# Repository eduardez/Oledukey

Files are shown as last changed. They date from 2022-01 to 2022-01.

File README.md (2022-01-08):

# Oledukey
Aun en fase de diseño, pero pinta flama.

# Renders
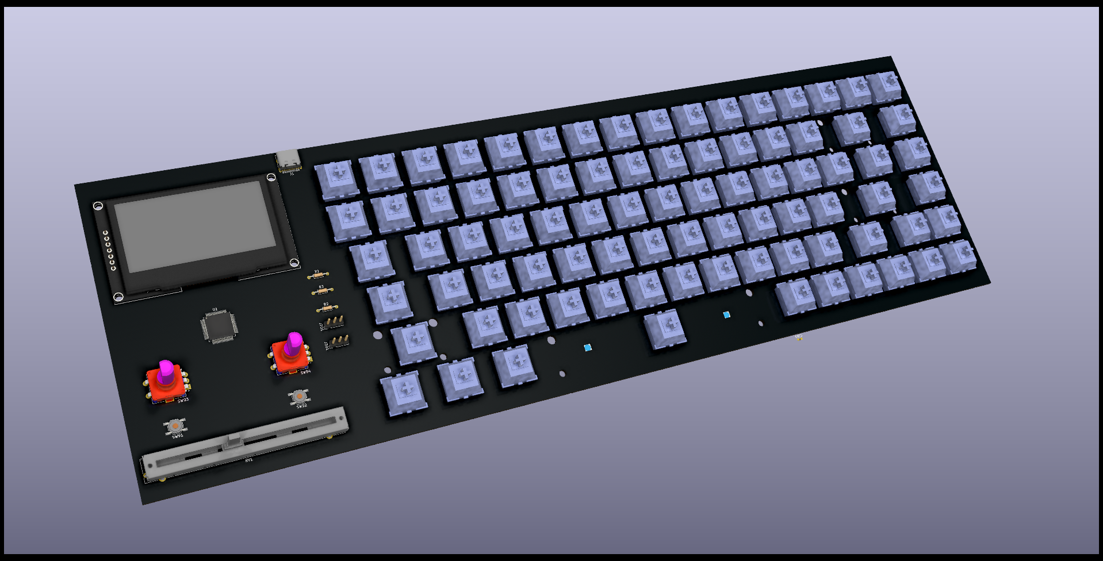
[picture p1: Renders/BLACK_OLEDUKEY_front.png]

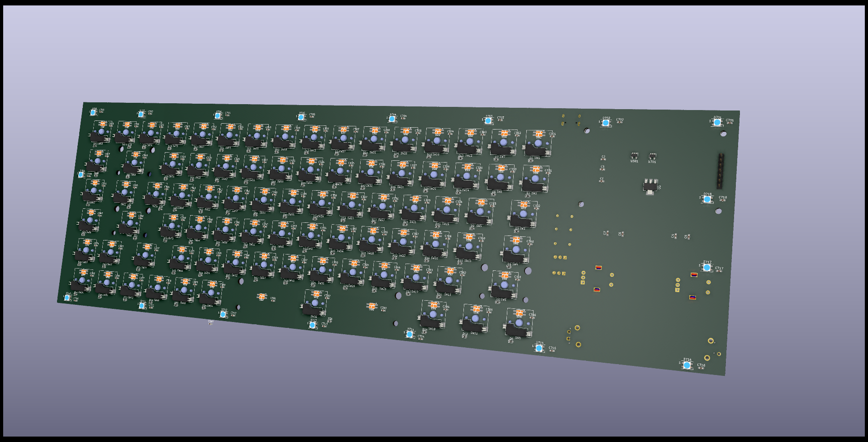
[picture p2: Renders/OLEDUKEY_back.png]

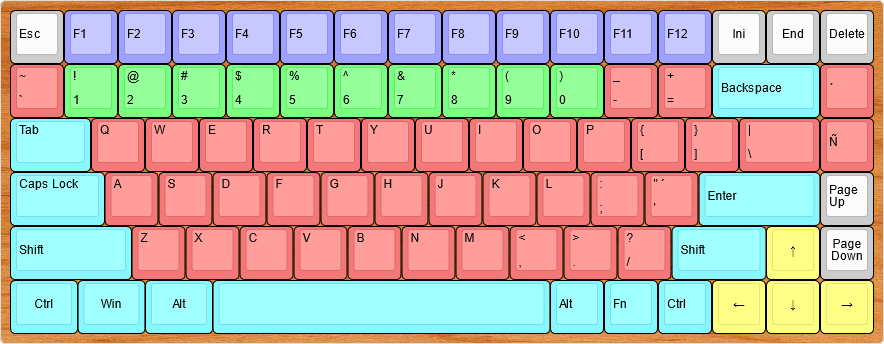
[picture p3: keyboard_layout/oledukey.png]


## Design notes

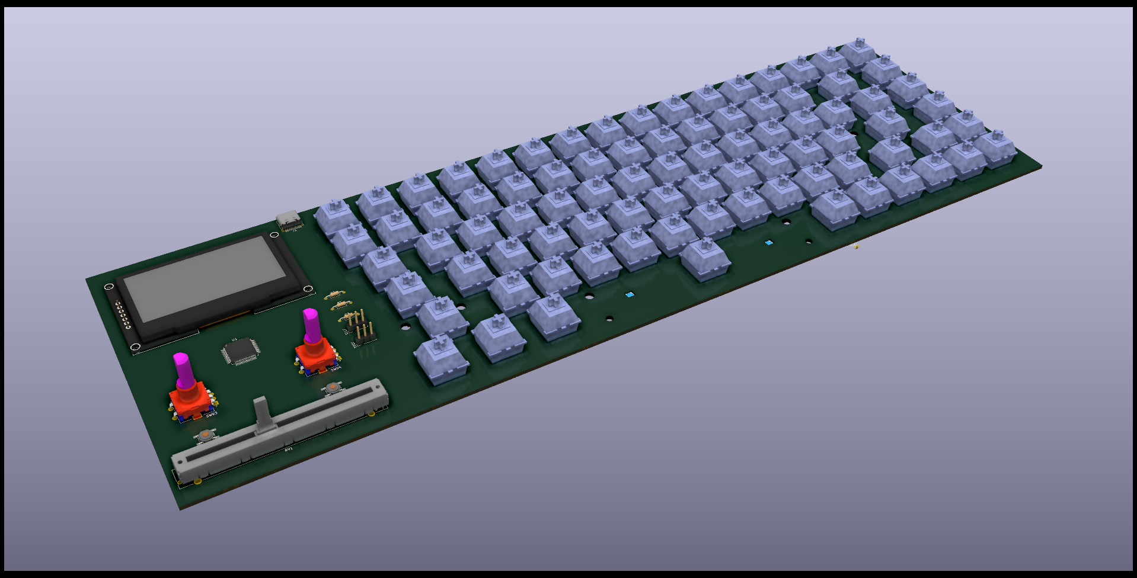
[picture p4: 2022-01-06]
Renders/OLEDUKEY_front.png

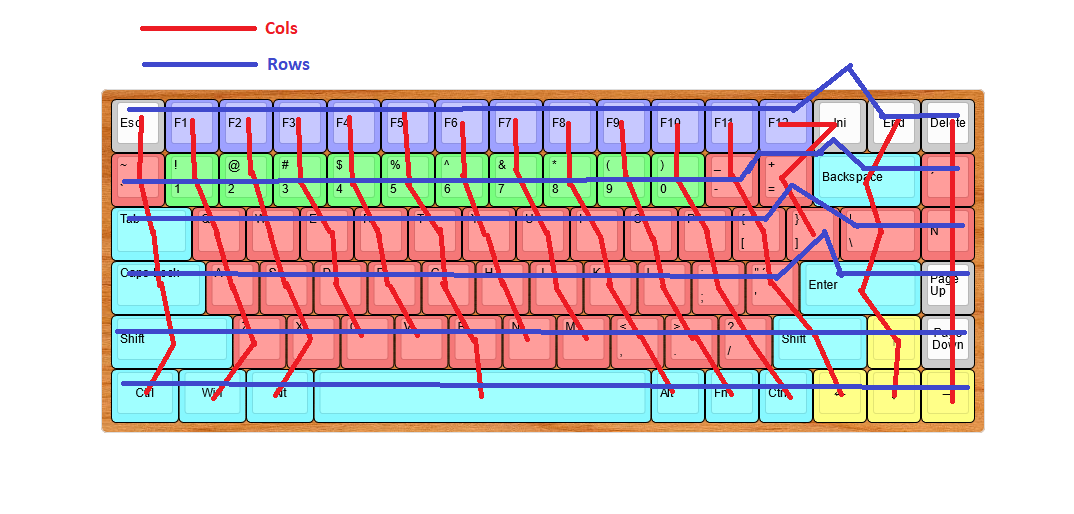
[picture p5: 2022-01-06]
keyboard_layout/oledukeyMATRIX.png

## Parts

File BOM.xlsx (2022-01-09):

Comprado | Parte | Valor | Quantity | Total buy | Value/unit | Total Price | Buy | Datasheet
 | Capacitor | 100nF | 109 |  | 0.0027 | 0.2943 | https://lcsc.com/product-detail/Multilayer-Ceramic-Capacitors-MLCC-SMD-SMT_FH-Guangdong-Fenghua-Advanced-Tech-0603F104M500NT_C42998.html | https://datasheet.lcsc.com/lcsc/1809211526_FH-Guangdong-Fenghua-Advanced-Tech-0603F104M500NT_C42998.pdf
 | Capacitor | 10uF | 2 |  | 0.0055 | 0.011 | https://lcsc.com/product-detail/Multilayer-Ceramic-Capacitors-MLCC-SMD-SMT_Samsung-Electro-Mechanics-CL10A106MP8NNNC_C85713.html | https://datasheet.lcsc.com/lcsc/1811021421_Samsung-Electro-Mechanics-CL10A106MP8NNNC_C85713.pdf
 | Diode | 1N4148WS | 84 |  | 0.0117 | 0.9828 | https://lcsc.com/product-detail/Switching-Diode_Shikues-1N4148WS_C110221.html | https://datasheet.lcsc.com/lcsc/1811131825_Shikues-1N4148WS_C110221.pdf
 | LED | SK6812MINI | 86 |  | 0.1147 | 9.8642 | https://es.aliexpress.com/item/32782295214.html | https://cdn-shop.adafruit.com/product-files/2686/SK6812MINI_REV.01-1-2.pdf
 | LED | SK6812MINI | 18 |  | 0.1099 | 1.9782 | https://es.aliexpress.com/item/32782295214.html | https://cdn-shop.adafruit.com/product-files/2686/SK6812MINI_REV.01-1-2.pdf
 | Connector | USB_C_TYPE-C-31-M-12 | 1 |  | 0.2453 | 0.2453 | https://lcsc.com/product-detail/USB-Connectors_Korean-Hroparts-Elec-TYPE-C-31-M-12_C165948.html | https://datasheet.lcsc.com/lcsc/2108131730_Korean-Hroparts-Elec-TYPE-C-31-M-12_C165948.pdf
 | Connector | Conn_01x03 | 2 |  | 0 | 0 | Home | ~
 | Resistor | 10k | 1 |  | 0 | 0 | Home | ~
 | Resistor | 5.1k | 2 |  | 0 | 0 | Home | ~
 | Potentiometer slide | R_POT | 1 |  | 11 | 11 | https://es.aliexpress.com/item/4000135544623.html | https://www.mouser.es/datasheet/2/54/pta-778345.pdf
 | Kalih hotswap | Kalih hotswap | 84 |  | 0.1 | 8.4 | https://kbdfans.com/products/mechanical-keyboard-switches-kailh-pcb-socket?variant=39678399447179 | ~
 | Stabilizers | Stabilizers | 1 |  | 15.9 | 15.9
 | Gatheron red | SW_Push | 84 |  | 0.2 | 16.8 |  | ~
 | Switch push | SW_Push | 2 |  | 0.3896 | 0.7792 | https://lcsc.com/product-detail/Tactile-Switches_E-Switch-TL3342F160QG_C2886898.html | https://datasheet.lcsc.com/lcsc/2109061530_E-Switch-TL3342F160QG_C2886898.pdf
 | Enconder | Rotary_Encoder_Switch | 2 |  | 0.32 | 0.64 | https://es.aliexpress.com/item/1744383771.html | https://www.farnell.com/datasheets/1837001.pdf
 | Brain | STM32F072RBTx | 1 |  | 12.4 | 12.4 | https://es.aliexpress.com/item/4001114352067.html | http://www.st.com/st-web-ui/static/active/en/resource/technical/document/datasheet/DM00090510.pdf
 | OLED | 2.42OLED | 1 |  | 17.77 | 17.77 | https://es.aliexpress.com/item/32965834123.html
 | Volt. Regulator | AMS1117-3.3 | 1 |  | 0.0852 | 0.0852 | https://lcsc.com/product-detail/Linear-Voltage-Regulators-LDO_PUOLOP-AMS1117-3-3_C351784.html | http://www.advanced-monolithic.com/pdf/ds1117.pdf
 | Buffered driver | 74LVC1G125 | 2 |  | 0.0791 | 0.1582 | https://lcsc.com/product-detail/Buffers-Drivers_Texas-Instruments-SN74LVC1G125DBVR_C23654.html | https://datasheet.lcsc.com/lcsc/1809200051_Texas-Instruments-SN74LVC1G125DBVR_C23654.pdf
 | PCB | Oledukey | 1 |  | 15.38 | 15.38
 |  |  | Por teclado
 |  | Total | 112.6884

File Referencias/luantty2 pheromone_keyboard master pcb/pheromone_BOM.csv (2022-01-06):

Comment | Description | Designator | Footprint | LibRef | Pins | Quantity | 긍뵀
LOGO | Desc | G***, | monitor | LibRef | 0 | 1
KiCad-Logo_5mm_Copper | Desc | REF**, | KiCad-Logo_5mm_Copper | LibRef | 0 | 1
WEEE-Logo_4.2x6mm_SilkScreen | Desc | REF**, | WEEE-Logo_4.2x6mm_SilkScreen | LibRef | 0 | 1
22p | Desc | C2,C1, | C_0805_2012Metric | LibRef | 2 | 2
1u | Desc | C3, | C_0805_2012Metric | LibRef | 2 | 1
100n | Desc | C7,C6,C5,C4, | C_0805_2012Metric | LibRef | 2 | 4
4.7u | Desc | C8, | C_0805_2012Metric | LibRef | 2 | 1
D | Desc | D1,D2,D3,D4,D5,D6,D7,D8,D9,D10,D11,D12,D13,D14,D15,D16,D17,D18,D19,D20,D21,D22,D23,D24,D25,D26,D27,D28,D29,D30,D31,D32,D33,D34,D35,D36,D37,D38,D39,D40,D41,D42,D43,D44,D45,D46,D47,D48,D49,D50,D51,D52,D53,D54,D55,D56,D57,D58,D59,D60,D61,D62,D63, | D_SOD-123 | LibRef | 2 | 63
LOGO | Desc | G***, | warning | LibRef | 0 | 1
LOGO | Desc | G***, | brand | LibRef | 0 | 1
LOGO | Desc | G***, | bulb | LibRef | 0 | 1
22 | Desc | R2,R1, | R_0805_2012Metric | LibRef | 2 | 2
10k | Desc | R4,R3, | R_0805_2012Metric | LibRef | 2 | 2
SW_PUSH | Desc | SW1, | SW_DIP_SPSTx01_Slide_6.7x4.1mm_W6.73mm_P2.54mm_LowProfile_JPin | LibRef | 2 | 1
ATMEGA32U4 | Desc | U1, | TQFP-44_10x10mm_Pitch0.8mm | LibRef | 44 | 1
Crystal_GND24 | Desc | Y1, | Crystal_SMD_3225-4Pin_3.2x2.5mm | LibRef | 4 | 1
Through Hole Items
Rotary_Encoder_Switch | Desc | E1, | RotaryEncoder_Alps_EC11E-Switch_Vertical_H20mm | LibRef | 7 | 1
KEYSW | Desc | K13,K56,K1,K2,K3,K4,K5,K6,K7,K8,K9,K10,K11,K12,K14,K15,K17,K18,K19,K20,K21,K22,K23,K24,K25,K26,K27,K28,K30,K31,K32,K33,K34,K35,K36,K37,K38,K39,K40,K41,K44,K45,K46,K47,K48,K49,K50,K51,K52,K53,K54,K55,K61,K62,K63, | MXOnly-1U-Hotswap | LibRef | 7 | 55
KEYSW | Desc | K16, | MXOnly-1.5U-Hotswap | LibRef | 7 | 1
KEYSW | Desc | K29, | MXOnly-1.75U-Hotswap | LibRef | 7 | 1
KEYSW | Desc | K42, | MXOnly-ISO-Hotswap | LibRef | 11 | 1
KEYSW | Desc | K43, | MXOnly-2U-Hotswap-ReversedStabilizers | LibRef | 11 | 1
KEYSW | Desc | K59,K58,K57, | MXOnly-1.25U-Hotswap | LibRef | 7 | 3
KEYSW | Desc | K60, | MXOnly-6.25U-Hotswap-ReversedStabilizers | LibRef | 11 | 1
Conn_01x04 | Desc | O1, | 0.91_SSD1306_OLED | LibRef | 4 | 1
R_POT | Desc | RV1, | potentiometer_slider_45mm | LibRef | 7 | 1
MountingHole_2.2mm_M2 | Desc | [SCREW],[SCREW],[SCREW],[SCREW],[SCREW],[SCREW], | MountingHole_2.2mm_M2 | LibRef | 1 | 6
USB_B_Micro | Desc | J1, | USB_Micro-B_Molex-105017-0001 | LibRef | 13 | 1
AVR-ISP-6 | Desc | P1, | PinHeader_2x03_P2.54mm_Vertical | LibRef | 6 | 1

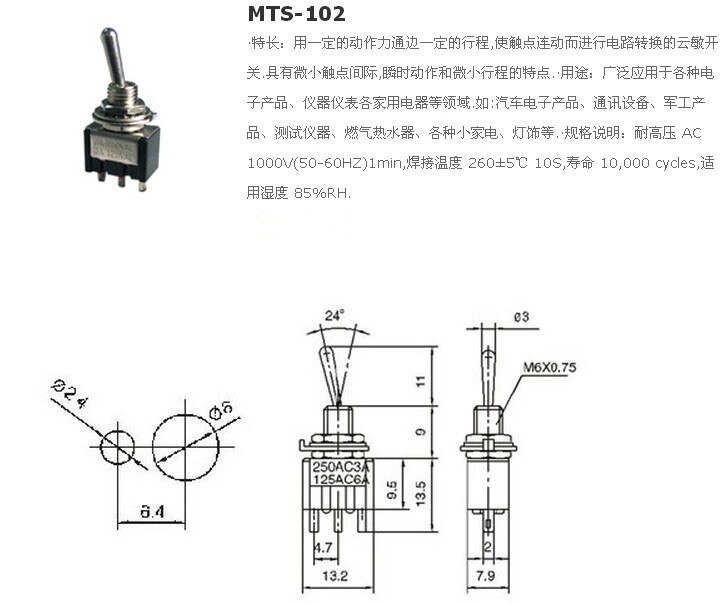
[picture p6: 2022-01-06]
Component sizes/HTB1nNfmtKOSBuNjy0Fdq6zDnVXaB.jpg

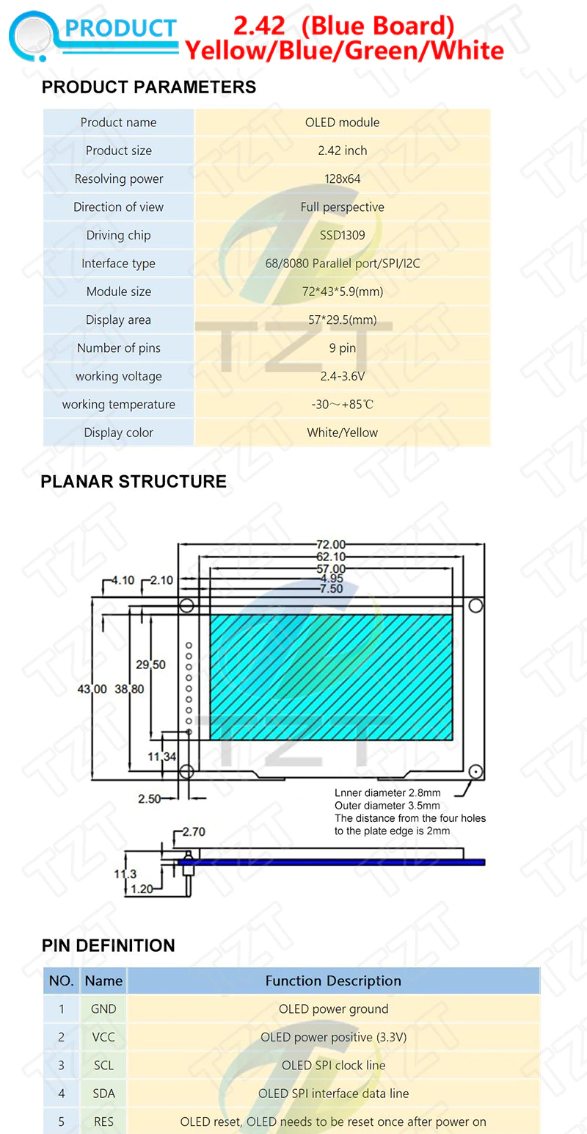
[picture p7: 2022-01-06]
Component sizes/H46aa8765ec844b979cd9eaf251b8d51fb.webp

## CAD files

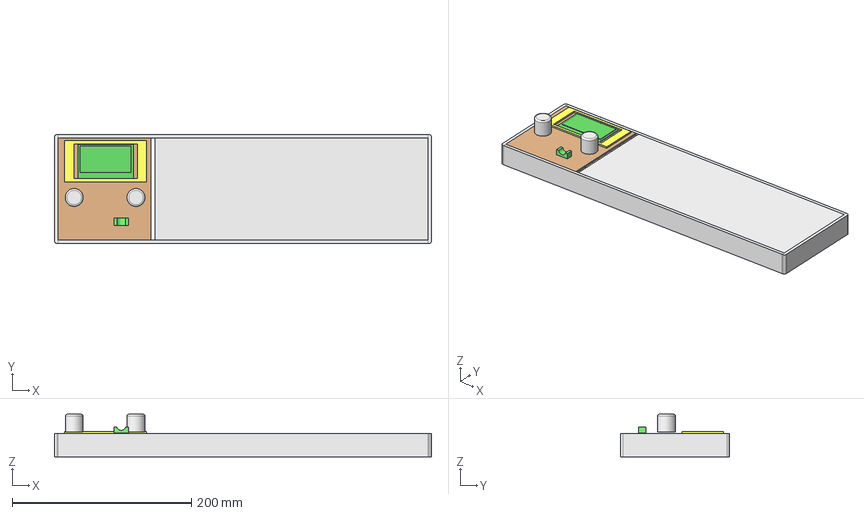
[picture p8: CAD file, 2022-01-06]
teclao_v2.FCStd
421.0 x 122.0 x 47.5 mm
Screen
GuitarCover2
Encoder1
Encoder
Slider
Keys
Mod_plate

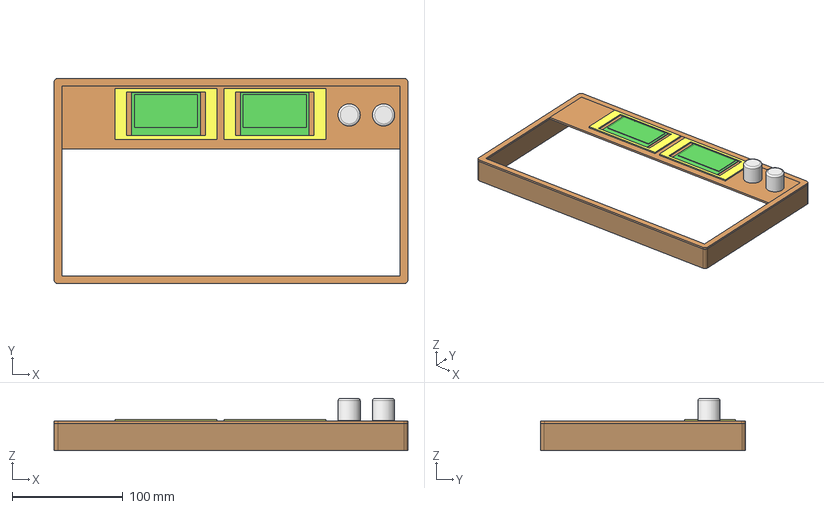
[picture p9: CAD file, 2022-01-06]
teclao.FCStd
319.0 x 185.0 x 47.0 mm
layer_top_2
Cubo002
GuitarCover2
GuitarCover1

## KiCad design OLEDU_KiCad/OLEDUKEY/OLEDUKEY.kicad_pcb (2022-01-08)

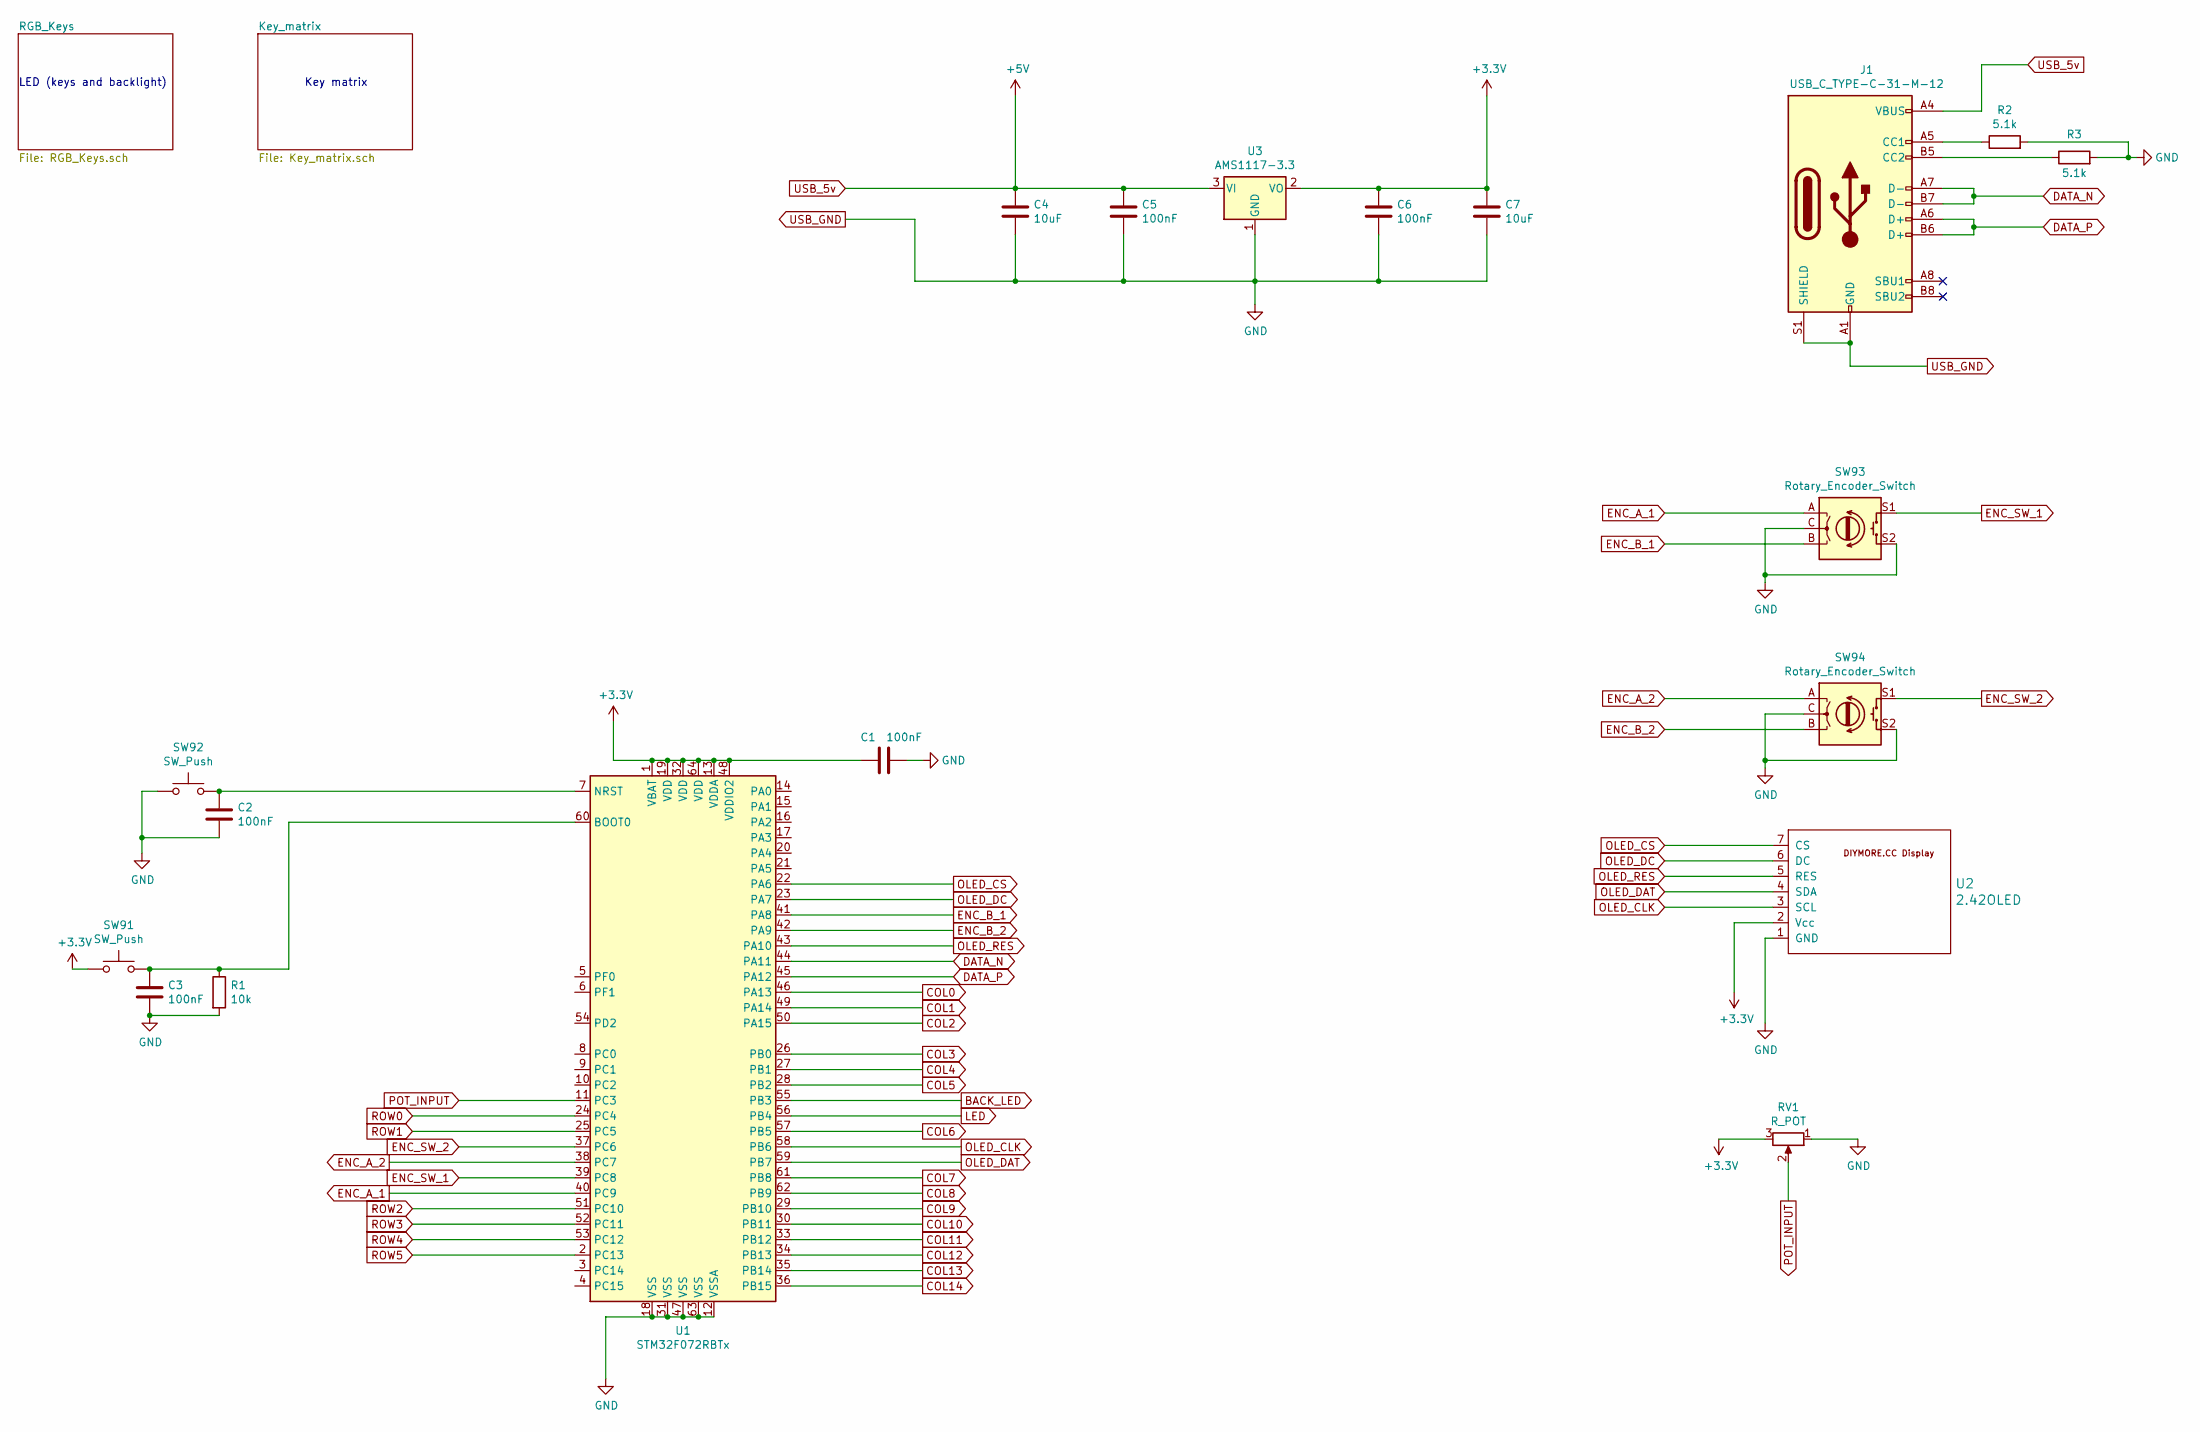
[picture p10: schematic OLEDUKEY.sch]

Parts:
C1, C2, C3, C5, C6: 100nF; C_0603_1608Metric_Pad1.08x0.95mm_HandSolder
C4, C7: 10uF; C_0603_1608Metric_Pad1.08x0.95mm_HandSolder
J1: USB_C_TYPE-C-31-M-12; USB_C_Receptacle_HRO_TYPE-C-31-M-12
R1: 10k; R_Axial_DIN0204_L3.6mm_D1.6mm_P7.62mm_Horizontal; Part URL Home
R2, R3: 5.1k; R_Axial_DIN0204_L3.6mm_D1.6mm_P7.62mm_Horizontal; Part URL Home
RV1: R_POT; Potentiometer_Bourns_PTA6043_Single_Slide
SW91, SW92: SW_Push; SW_SPST_TL3342
SW93, SW94: Rotary_Encoder_Switch; RotaryEncoder_Alps_EC11E-Switch_Vertical_H20mm
U1: STM32F072RBTx; LQFP-64_10x10mm_P0.5mm
U2: 2.42OLED; DIYMORE.CC
U3: AMS1117-3.3; SOT-223-3_TabPin2

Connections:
+3V3: C1.1, C6.1, C7.1, RV1.3, SW91.1, U1.1 (VBAT), U1.13 (VDDA), U1.19 (VDD), U1.32 (VDD), U1.48 (VDDIO2), U1.64 (VDD), U2.2 (Vcc), U3.2 (VO)
BACK_LED: U1.55 (PB3); also elsewhere on the board
COL0: U1.46 (PA13); also elsewhere on the board
COL1: U1.49 (PA14); also elsewhere on the board
COL2: U1.50 (PA15); also elsewhere on the board
COL3: U1.26 (PB0); also elsewhere on the board
COL4: U1.27 (PB1); also elsewhere on the board
COL5: U1.28 (PB2); also elsewhere on the board
COL6: U1.57 (PB5); also elsewhere on the board
COL7: U1.61 (PB8); also elsewhere on the board
COL8: U1.62 (PB9); also elsewhere on the board
COL9: U1.29 (PB10); also elsewhere on the board
COL10: U1.30 (PB11); also elsewhere on the board
COL11: U1.33 (PB12); also elsewhere on the board
COL12: U1.34 (PB13); also elsewhere on the board
COL13: U1.35 (PB14); also elsewhere on the board
COL14: U1.36 (PB15); also elsewhere on the board
DATA_N: J1.A7 (D-), J1.B7 (D-), U1.44 (PA11)
DATA_P: J1.A6 (D+), J1.B6 (D+), U1.45 (PA12)
ENC_A_1: SW93.A, U1.40 (PC9)
ENC_A_2: SW94.A, U1.38 (PC7)
ENC_B_1: SW93.B, U1.41 (PA8)
ENC_B_2: SW94.B, U1.42 (PA9)
ENC_SW_1: SW93.S1, U1.39 (PC8)
ENC_SW_2: SW94.S1, U1.37 (PC6)
LED: U1.56 (PB4); also elsewhere on the board
unnamed: C2.1, SW92.2, U1.7 (NRST)
unnamed: C3.1, R1.1, SW91.2, U1.60 (BOOT0)
unnamed: J1.A5 (CC1), R2.1
unnamed: J1.B5 (CC2), R3.1
OLED_CLK: U1.58 (PB6), U2.3 (SCL)
OLED_CS: U1.22 (PA6), U2.7 (CS)
OLED_DAT: U1.59 (PB7), U2.4 (SDA)
OLED_DC: U1.23 (PA7), U2.6 (DC)
OLED_RES: U1.43 (PA10), U2.5 (RES)
POT_INPUT: RV1.2, U1.11 (PC3)
ROW0: U1.24 (PC4); also elsewhere on the board
ROW1: U1.25 (PC5); also elsewhere on the board
ROW2: U1.51 (PC10); also elsewhere on the board
ROW3: U1.52 (PC11); also elsewhere on the board
ROW4: U1.53 (PC12); also elsewhere on the board
ROW5: U1.2 (PC13); also elsewhere on the board
USB_GND: C1.2, C2.2, C3.2, C4.2, C5.2, C6.2, C7.2, J1.A1 (GND), J1.A12 (GND), J1.B1 (GND), J1.B12 (GND), J1.S1 (SHIELD), R1.2, R2.2, R3.2, RV1.1, SW92.1, SW93.C, SW93.S2, SW94.C, SW94.S2, U1.12 (VSSA), U1.18 (VSS), U1.31 (VSS), U1.47 (VSS), U1.63 (VSS), U2.1 (GND), U3.1 (GND); also elsewhere on the board

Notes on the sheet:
LED (keys and backlight)
Key matrix

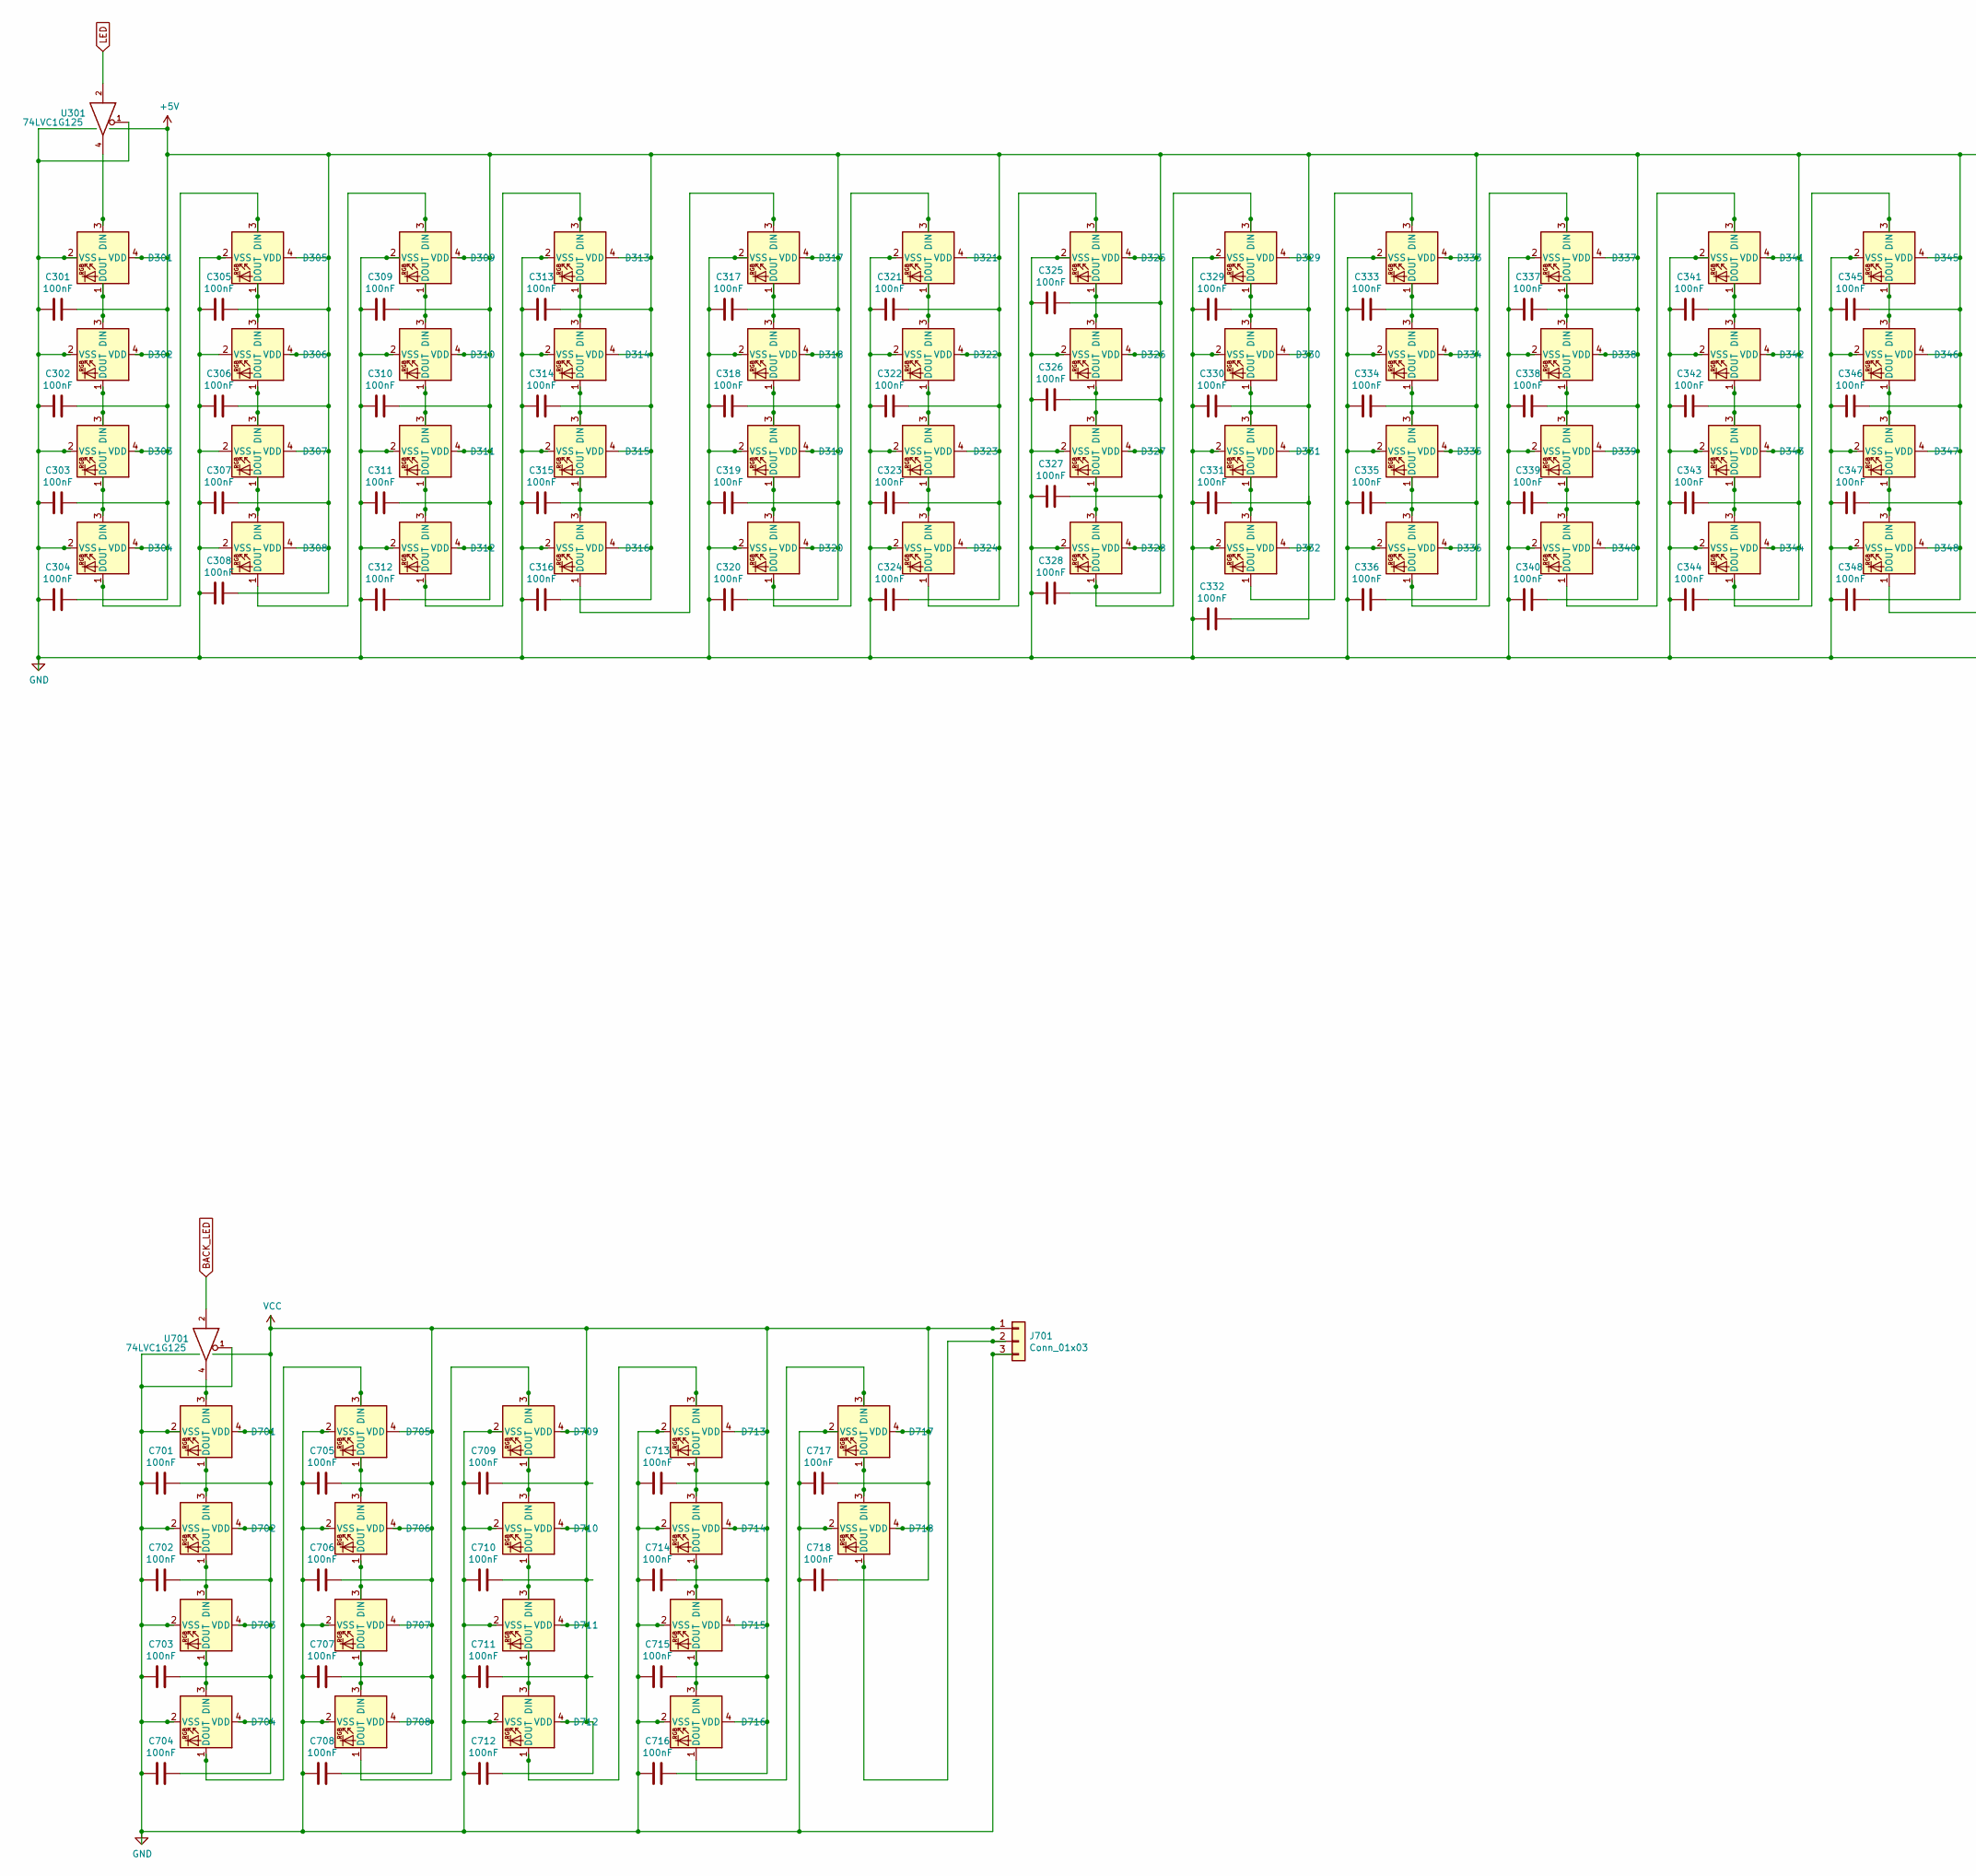
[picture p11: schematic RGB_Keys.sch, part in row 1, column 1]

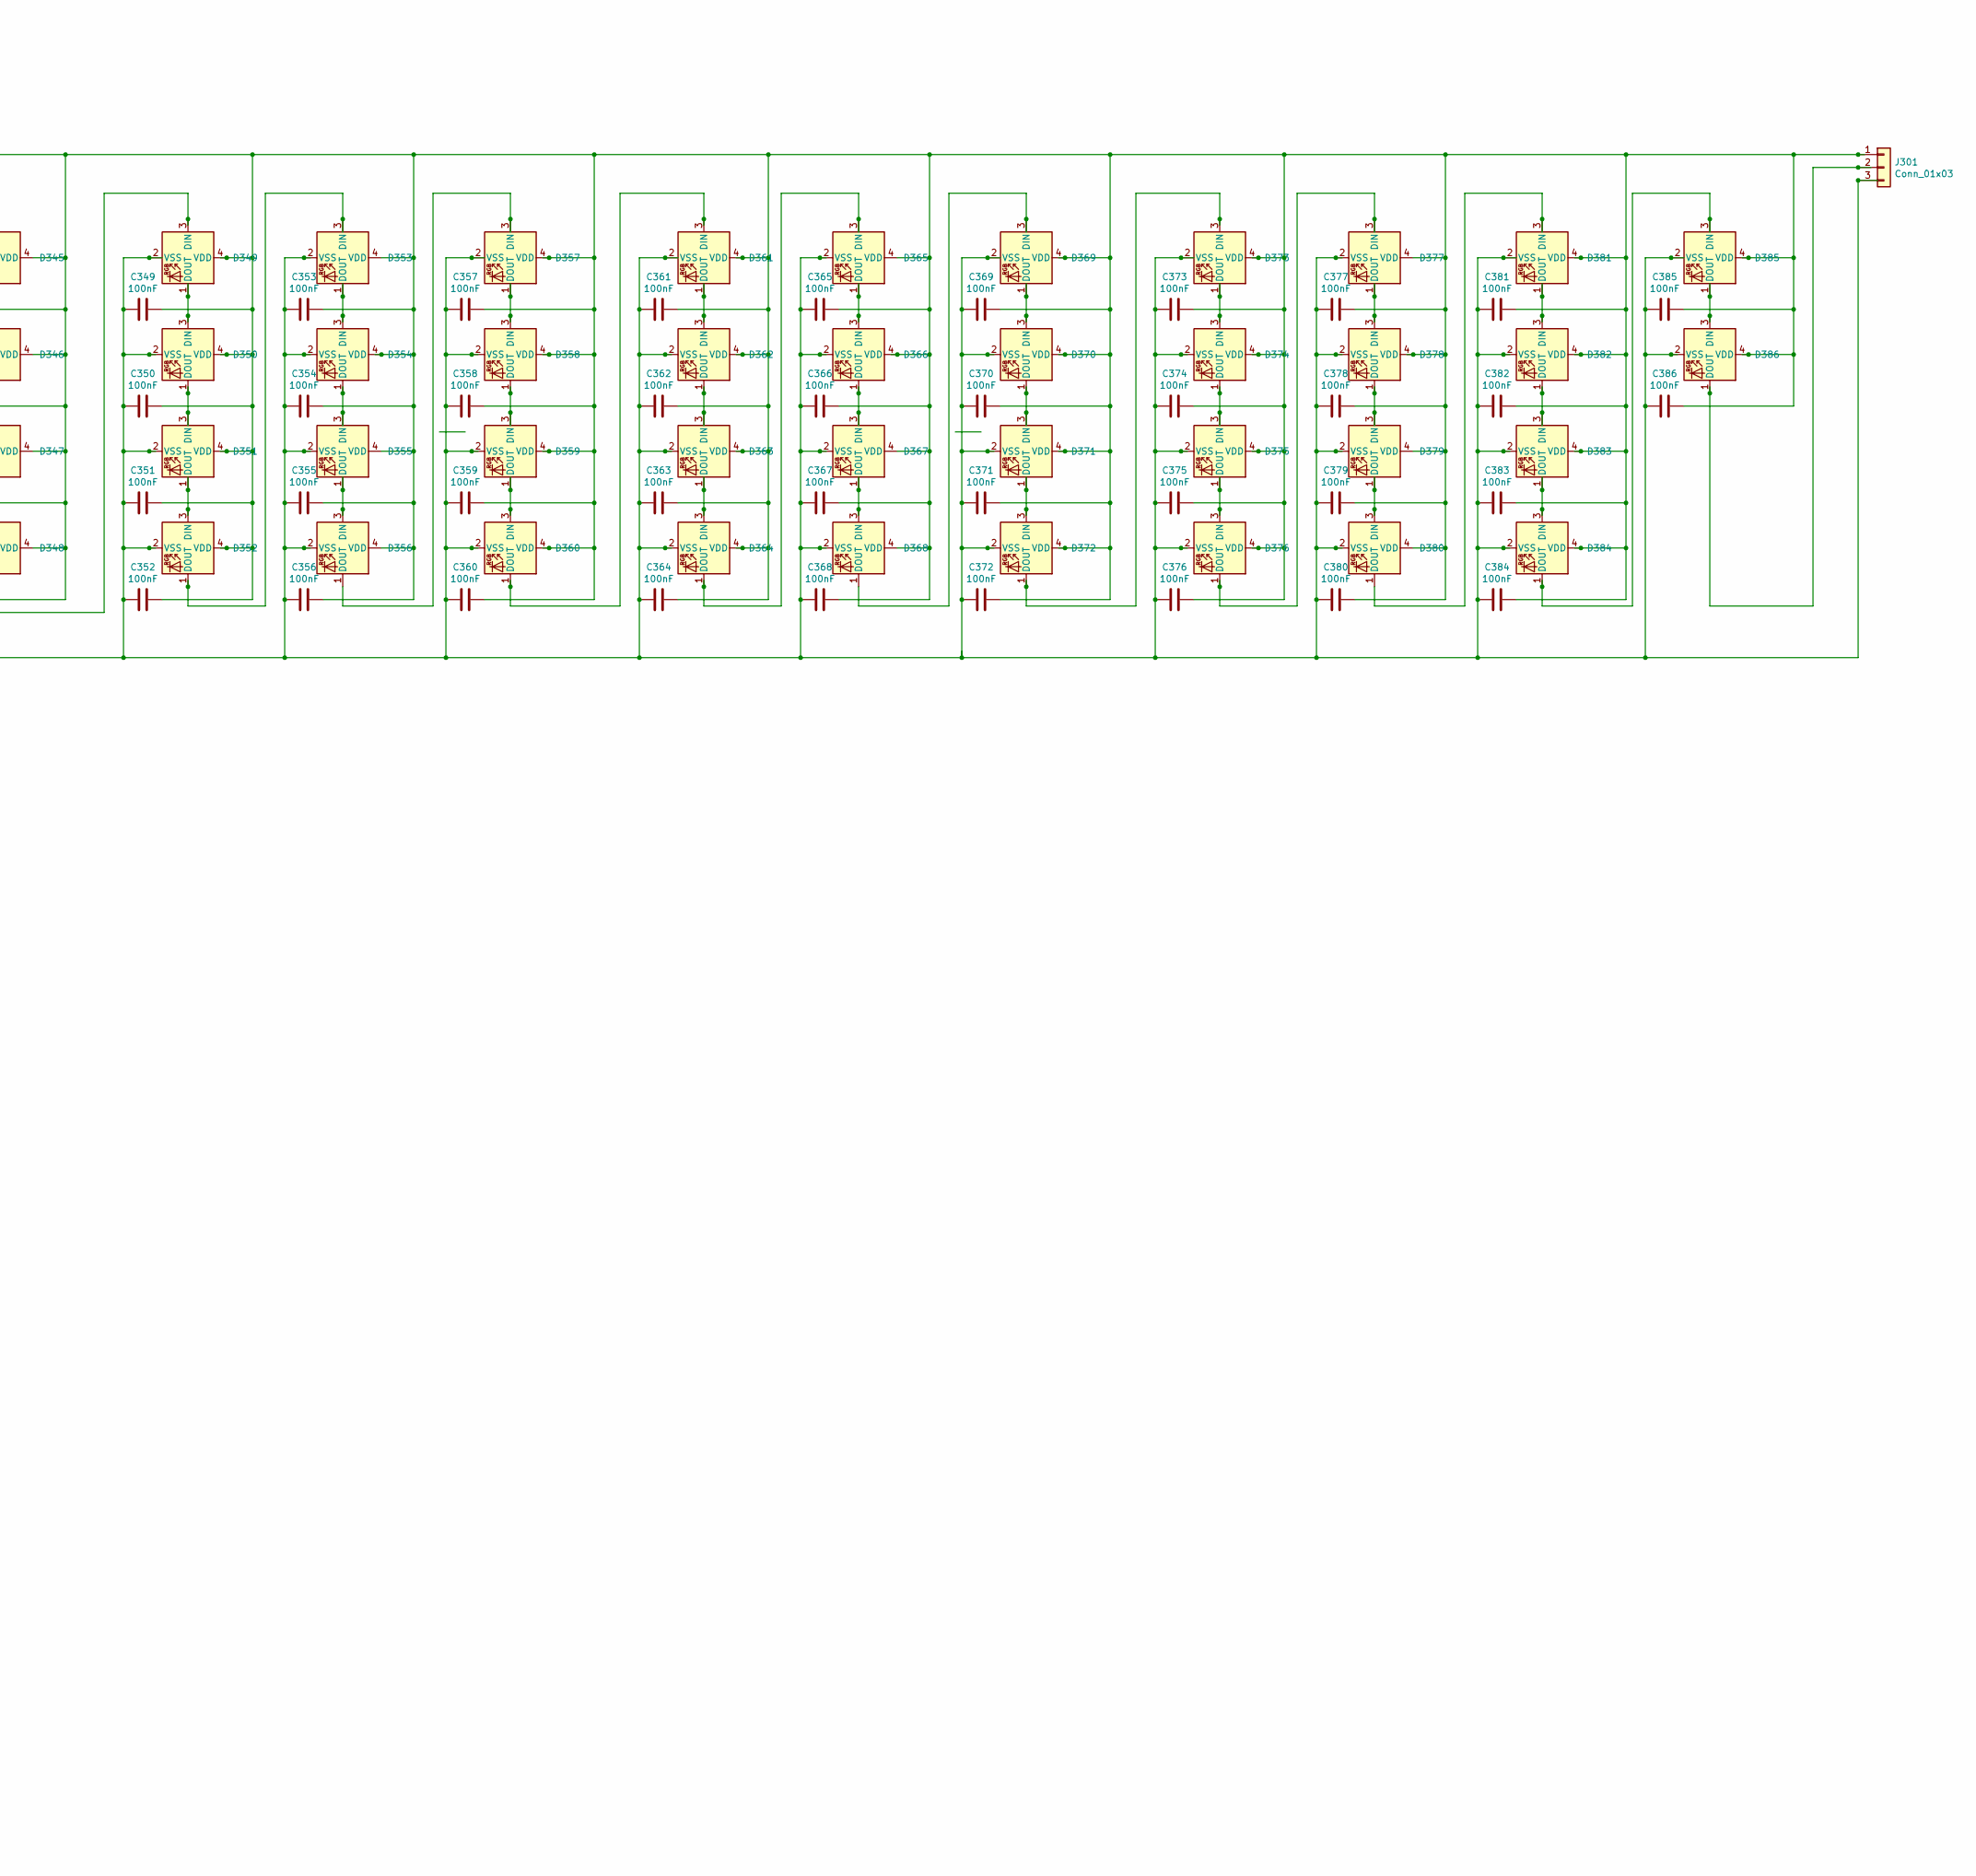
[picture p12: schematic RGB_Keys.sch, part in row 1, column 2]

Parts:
C301, C302, C303, C304, C305, C306, C307, C308, C309, C310, C311, C312, C313, C314, C315, C316, C317, C318, C319, C320, C321, C322, C323, C324, C325, C326, C327, C328, C329, C330, C331, C332, C333, C334, C335, C336, C337, C338, C339, C340, C341, C342, C343, C344, C345, C346, C347, C348, C349, C350, C351, C352, C353, C354, C355, C356, C357, C358, C359, C360, C361, C362, C363, C364, C365, C366, C367, C368, C369, C370, C371, C372, C373, C374, C375, C376, C377, C378, C379, C380, C381, C382, C383, C384, C385, C386, C701, C702, C703, C704, C705, C706, C707, C708, C709, C710, C711, C712, C713, C714, C715, C716, C717, C718: 100nF; C_0603_1608Metric_Pad1.08x0.95mm_HandSolder
D301, D302, D303, D304, D305, D306, D307, D308, D309, D310, D311, D312, D313, D314, D315, D316, D317, D318, D319, D320, D321, D322, D323, D324, D325, D326, D327, D328, D329, D330, D331, D332, D333, D334, D335, D336, D337, D338, D339, D340, D341, D342, D343, D344, D345, D346, D347, D348, D349, D350, D351, D352, D353, D354, D355, D356, D357, D358, D359, D360, D361, D362, D363, D364, D365, D366, D367, D368, D369, D370, D371, D372, D373, D374, D375, D376, D377, D378, D379, D380, D381, D382, D383, D384, D385, D386: SK6812MINI; SK6812-MINI-E
D701, D702, D703, D704, D705, D706, D707, D708, D709, D710, D711, D712, D713, D714, D715, D716, D717, D718: SK6812MINI; LED_SK6812MINI_PLCC4_3.5x3.5mm_P1.75mm
J301, J701: Conn_01x03; PinHeader_1x03_P2.54mm_Vertical; Part URL Home
U301, U701: 74LVC1G125; SOT-23-5

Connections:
BACK_LED: U701.2; also elsewhere on the board
LED: U301.2; also elsewhere on the board
unnamed: D301.1 (DOUT), D302.3 (DIN)
unnamed: D301.3 (DIN), U301.4
unnamed: D302.1 (DOUT), D303.3 (DIN)
unnamed: D303.1 (DOUT), D304.3 (DIN)
unnamed: D304.1 (DOUT), D305.3 (DIN)
unnamed: D305.1 (DOUT), D306.3 (DIN)
unnamed: D306.1 (DOUT), D307.3 (DIN)
unnamed: D307.1 (DOUT), D308.3 (DIN)
unnamed: D308.1 (DOUT), D309.3 (DIN)
unnamed: D309.1 (DOUT), D310.3 (DIN)
unnamed: D310.1 (DOUT), D311.3 (DIN)
unnamed: D311.1 (DOUT), D312.3 (DIN)
unnamed: D312.1 (DOUT), D313.3 (DIN)
unnamed: D313.1 (DOUT), D314.3 (DIN)
unnamed: D314.1 (DOUT), D315.3 (DIN)
unnamed: D315.1 (DOUT), D316.3 (DIN)
unnamed: D316.1 (DOUT), D317.3 (DIN)
unnamed: D317.1 (DOUT), D318.3 (DIN)
unnamed: D318.1 (DOUT), D319.3 (DIN)
unnamed: D319.1 (DOUT), D320.3 (DIN)
unnamed: D320.1 (DOUT), D321.3 (DIN)
unnamed: D321.1 (DOUT), D322.3 (DIN)
unnamed: D322.1 (DOUT), D323.3 (DIN)
unnamed: D323.1 (DOUT), D324.3 (DIN)
unnamed: D324.1 (DOUT), D325.3 (DIN)
unnamed: D325.1 (DOUT), D326.3 (DIN)
unnamed: D326.1 (DOUT), D327.3 (DIN)
unnamed: D327.1 (DOUT), D328.3 (DIN)
unnamed: D328.1 (DOUT), D329.3 (DIN)
unnamed: D329.1 (DOUT), D330.3 (DIN)
unnamed: D330.1 (DOUT), D331.3 (DIN)
unnamed: D331.1 (DOUT), D332.3 (DIN)
unnamed: D332.1 (DOUT), D333.3 (DIN)
unnamed: D333.1 (DOUT), D334.3 (DIN)
unnamed: D334.1 (DOUT), D335.3 (DIN)
unnamed: D335.1 (DOUT), D336.3 (DIN)
unnamed: D336.1 (DOUT), D337.3 (DIN)
unnamed: D337.1 (DOUT), D338.3 (DIN)
unnamed: D338.1 (DOUT), D339.3 (DIN)
unnamed: D339.1 (DOUT), D340.3 (DIN)
unnamed: D340.1 (DOUT), D341.3 (DIN)
unnamed: D341.1 (DOUT), D342.3 (DIN)
unnamed: D342.1 (DOUT), D343.3 (DIN)
unnamed: D343.1 (DOUT), D344.3 (DIN)
unnamed: D344.1 (DOUT), D345.3 (DIN)
unnamed: D345.1 (DOUT), D346.3 (DIN)
unnamed: D346.1 (DOUT), D347.3 (DIN)
unnamed: D347.1 (DOUT), D348.3 (DIN)
unnamed: D348.1 (DOUT), D349.3 (DIN)
unnamed: D349.1 (DOUT), D350.3 (DIN)
unnamed: D350.1 (DOUT), D351.3 (DIN)
unnamed: D351.1 (DOUT), D352.3 (DIN)
unnamed: D352.1 (DOUT), D353.3 (DIN)
unnamed: D353.1 (DOUT), D354.3 (DIN)
unnamed: D354.1 (DOUT), D355.3 (DIN)
unnamed: D355.1 (DOUT), D356.3 (DIN)
unnamed: D356.1 (DOUT), D357.3 (DIN)
unnamed: D357.1 (DOUT), D358.3 (DIN)
unnamed: D358.1 (DOUT), D359.3 (DIN)
unnamed: D359.1 (DOUT), D360.3 (DIN)
unnamed: D360.1 (DOUT), D361.3 (DIN)
unnamed: D361.1 (DOUT), D362.3 (DIN)
unnamed: D362.1 (DOUT), D363.3 (DIN)
unnamed: D363.1 (DOUT), D364.3 (DIN)
unnamed: D364.1 (DOUT), D365.3 (DIN)
unnamed: D365.1 (DOUT), D366.3 (DIN)
unnamed: D366.1 (DOUT), D367.3 (DIN)
unnamed: D367.1 (DOUT), D368.3 (DIN)
unnamed: D368.1 (DOUT), D369.3 (DIN)
unnamed: D369.1 (DOUT), D370.3 (DIN)
unnamed: D370.1 (DOUT), D371.3 (DIN)
unnamed: D371.1 (DOUT), D372.3 (DIN)
unnamed: D372.1 (DOUT), D373.3 (DIN)
unnamed: D373.1 (DOUT), D374.3 (DIN)
unnamed: D374.1 (DOUT), D375.3 (DIN)
unnamed: D375.1 (DOUT), D376.3 (DIN)
unnamed: D376.1 (DOUT), D377.3 (DIN)
unnamed: D377.1 (DOUT), D378.3 (DIN)
unnamed: D378.1 (DOUT), D379.3 (DIN)
unnamed: D379.1 (DOUT), D380.3 (DIN)
unnamed: D380.1 (DOUT), D381.3 (DIN)
unnamed: D381.1 (DOUT), D382.3 (DIN)
unnamed: D382.1 (DOUT), D383.3 (DIN)
unnamed: D383.1 (DOUT), D384.3 (DIN)
unnamed: D384.1 (DOUT), D385.3 (DIN)
unnamed: D385.1 (DOUT), D386.3 (DIN)
unnamed: D386.1 (DOUT), J301.2
unnamed: D701.1 (DOUT), D702.3 (DIN)
unnamed: D701.3 (DIN), U701.4
unnamed: D702.1 (DOUT), D703.3 (DIN)
unnamed: D703.1 (DOUT), D704.3 (DIN)
unnamed: D704.1 (DOUT), D705.3 (DIN)
unnamed: D705.1 (DOUT), D706.3 (DIN)
unnamed: D706.1 (DOUT), D707.3 (DIN)
unnamed: D707.1 (DOUT), D708.3 (DIN)
unnamed: D708.1 (DOUT), D709.3 (DIN)
unnamed: D709.1 (DOUT), D710.3 (DIN)
unnamed: D710.1 (DOUT), D711.3 (DIN)
unnamed: D711.1 (DOUT), D712.3 (DIN)
unnamed: D712.1 (DOUT), D713.3 (DIN)
unnamed: D713.1 (DOUT), D714.3 (DIN)
unnamed: D714.1 (DOUT), D715.3 (DIN)
unnamed: D715.1 (DOUT), D716.3 (DIN)
unnamed: D716.1 (DOUT), D717.3 (DIN)
unnamed: D717.1 (DOUT), D718.3 (DIN)
unnamed: D718.1 (DOUT), J701.2
USB_GND: C301.2, C302.2, C303.2, C304.2, C305.2, C306.2, C307.2, C308.2, C309.2, C310.2, C311.2, C312.2, C313.2, C314.2, C315.2, C316.2, C317.2, C318.2, C319.2, C320.2, C321.2, C322.2, C323.2, C324.2, C325.2, C326.2, C327.2, C328.2, C329.2, C330.2, C331.2, C332.2, C333.2, C334.2, C335.2, C336.2, C337.2, C338.2, C339.2, C340.2, C341.2, C342.2, C343.2, C344.2, C345.2, C346.2, C347.2, C348.2, C349.2, C350.2, C351.2, C352.2, C353.2, C354.2, C355.2, C356.2, C357.2, C358.2, C359.2, C360.2, C361.2, C362.2, C363.2, C364.2, C365.2, C366.2, C367.2, C368.2, C369.2, C370.2, C371.2, C372.2, C373.2, C374.2, C375.2, C376.2, C377.2, C378.2, C379.2, C380.2, C381.2, C382.2, C383.2, C384.2, C385.2, C386.2, C701.2, C702.2, C703.2, C704.2, C705.2, C706.2, C707.2, C708.2, C709.2, C710.2, C711.2, C712.2, C713.2, C714.2, C715.2, C716.2, C717.2, C718.2, D301.2 (VSS), D302.2 (VSS), D303.2 (VSS), D304.2 (VSS), D305.2 (VSS), D306.2 (VSS), D307.2 (VSS), D308.2 (VSS), D309.2 (VSS), D310.2 (VSS), D311.2 (VSS), D312.2 (VSS), D313.2 (VSS), D314.2 (VSS), D315.2 (VSS), D316.2 (VSS), D317.2 (VSS), D318.2 (VSS), D319.2 (VSS), D320.2 (VSS), D321.2 (VSS), D322.2 (VSS), D323.2 (VSS), D324.2 (VSS), D325.2 (VSS), D326.2 (VSS), D327.2 (VSS), D328.2 (VSS), D329.2 (VSS), D330.2 (VSS), D331.2 (VSS), D332.2 (VSS), D333.2 (VSS), D334.2 (VSS), D335.2 (VSS), D336.2 (VSS), D337.2 (VSS), D338.2 (VSS), D339.2 (VSS), D340.2 (VSS), D341.2 (VSS), D342.2 (VSS), D343.2 (VSS), D344.2 (VSS), D345.2 (VSS), D346.2 (VSS), D347.2 (VSS), D348.2 (VSS), D349.2 (VSS), D350.2 (VSS), D351.2 (VSS), D352.2 (VSS), D353.2 (VSS), D354.2 (VSS), D355.2 (VSS), D356.2 (VSS), D357.2 (VSS), D358.2 (VSS), D359.2 (VSS), D360.2 (VSS), D361.2 (VSS), D362.2 (VSS), D363.2 (VSS), D364.2 (VSS), D365.2 (VSS), D366.2 (VSS), D367.2 (VSS), D368.2 (VSS), D369.2 (VSS), D370.2 (VSS), D371.2 (VSS), D372.2 (VSS), D373.2 (VSS), D374.2 (VSS), D375.2 (VSS), D376.2 (VSS), D377.2 (VSS), D378.2 (VSS), D379.2 (VSS), D380.2 (VSS), D381.2 (VSS), D382.2 (VSS), D383.2 (VSS), D384.2 (VSS), D385.2 (VSS), D386.2 (VSS), D701.2 (VSS), D702.2 (VSS), D703.2 (VSS), D704.2 (VSS), D705.2 (VSS), D706.2 (VSS), D707.2 (VSS), D708.2 (VSS), D709.2 (VSS), D710.2 (VSS), D711.2 (VSS), D712.2 (VSS), D713.2 (VSS), D714.2 (VSS), D715.2 (VSS), D716.2 (VSS), D717.2 (VSS), D718.2 (VSS), J301.3, J701.3, U301.1, U301.3 (GND), U701.1, U701.3 (GND); also elsewhere on the board

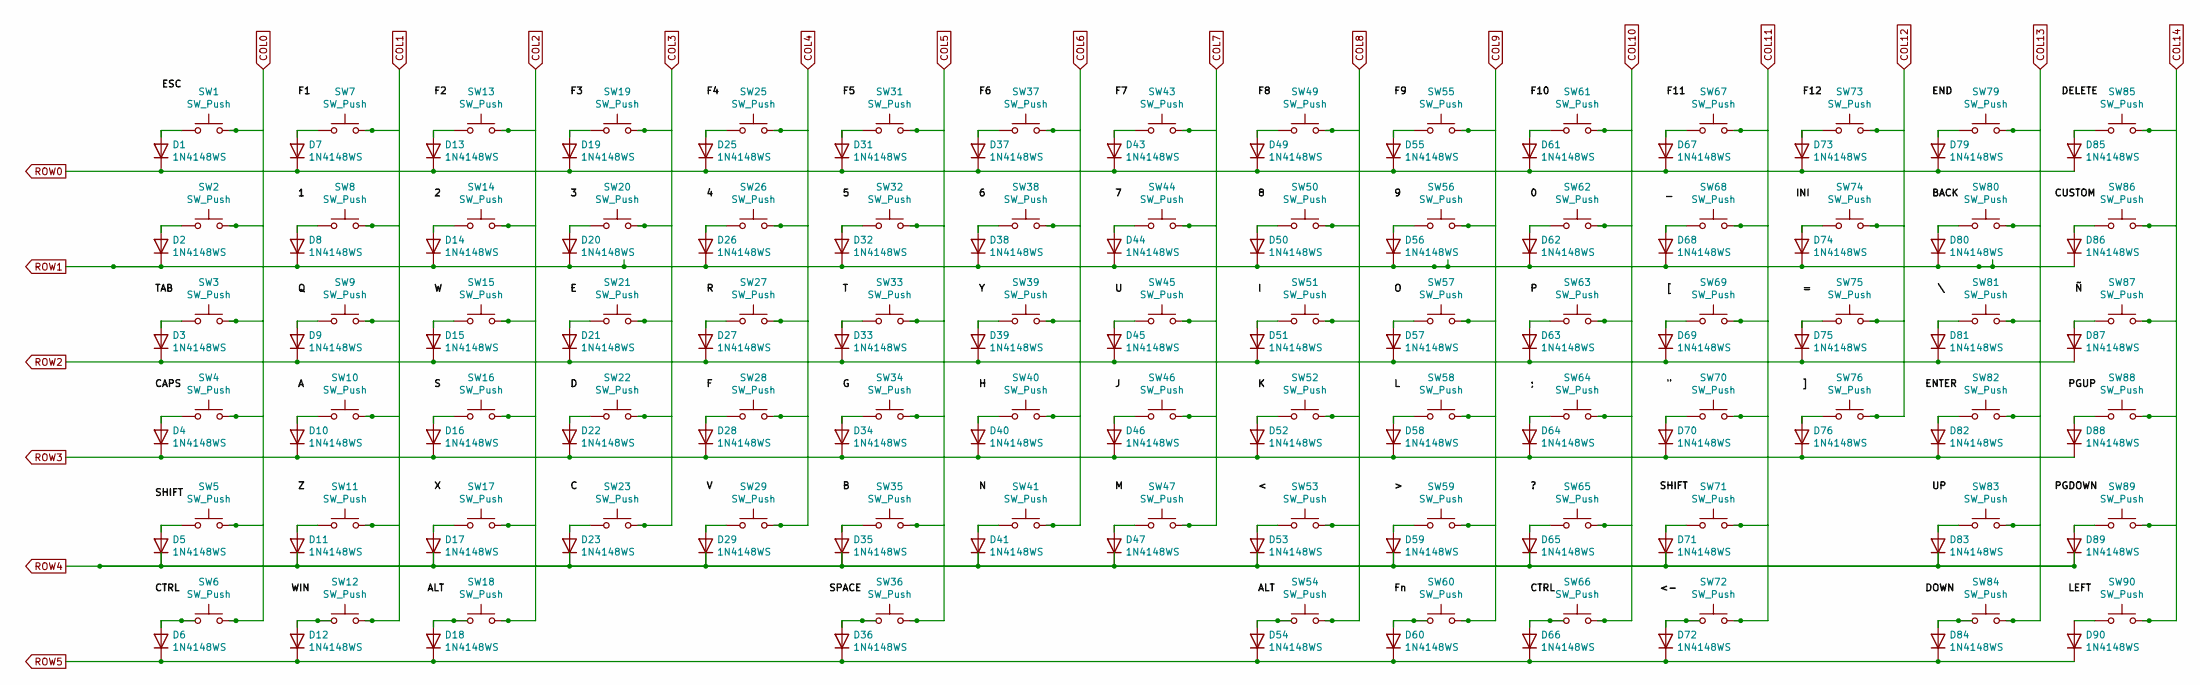
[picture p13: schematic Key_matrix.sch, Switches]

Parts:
D1, D2, D3, D4, D5, D6, D7, D8, D9, D10, D11, D12, D13, D14, D15, D16, D17, D18, D19, D20, D21, D22, D23, D25, D26, D27, D28, D29, D31, D32, D33, D34, D35, D36, D37, D38, D39, D40, D41, D43, D44, D45, D46, D47, D49, D50, D51, D52, D53, D54, D55, D56, D57, D58, D59, D60, D61, D62, D63, D64, D65, D66, D67, D68, D69, D70, D71, D72, D73, D74, D75, D76, D79, D80, D81, D82, D83, D84, D85, D86, D87, D88, D89, D90: 1N4148WS; D_0603_1608Metric
SW1, SW2, SW7, SW8, SW9, SW10, SW11, SW13, SW14, SW15, SW16, SW17, SW19, SW20, SW21, SW22, SW23, SW25, SW26, SW27, SW28, SW29, SW31, SW32, SW33, SW34, SW35, SW37, SW38, SW39, SW40, SW41, SW43, SW44, SW45, SW46, SW47, SW49, SW50, SW51, SW52, SW53, SW54, SW55, SW56, SW57, SW58, SW59, SW60, SW61, SW62, SW63, SW64, SW65, SW66, SW67, SW68, SW69, SW70, SW72, SW73, SW74, SW75, SW76, SW79, SW83, SW84, SW85, SW86, SW87, SW88, SW89, SW90: SW_Push; SW_Cherry_MX_1.00u_PCB
SW3, SW81: SW_Push; SW_Cherry_MX_1.50u_PCB
SW4, SW71: SW_Push; SW_Cherry_MX_1.75u_PCB
SW5, SW82: SW_Push; SW_Cherry_MX_2.25u_PCB
SW6, SW12, SW18: SW_Push; SW_Cherry_MX_1.25u_PCB
SW36: SW_Push; SW_Cherry_MX_6.25u_PCB
SW80: SW_Push; SW_Cherry_MX_2.00u_PCB

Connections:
COL0: SW1.2, SW2.2, SW3.2, SW4.2, SW5.2, SW6.2; also elsewhere on the board
COL1: SW7.2, SW8.2, SW9.2, SW10.2, SW11.2, SW12.2; also elsewhere on the board
COL2: SW13.2, SW14.2, SW15.2, SW16.2, SW17.2, SW18.2; also elsewhere on the board
COL3: SW19.2, SW20.2, SW21.2, SW22.2, SW23.2; also elsewhere on the board
COL4: SW25.2, SW26.2, SW27.2, SW28.2, SW29.2; also elsewhere on the board
COL5: SW31.2, SW32.2, SW33.2, SW34.2, SW35.2, SW36.2; also elsewhere on the board
COL6: SW37.2, SW38.2, SW39.2, SW40.2, SW41.2; also elsewhere on the board
COL7: SW43.2, SW44.2, SW45.2, SW46.2, SW47.2; also elsewhere on the board
COL8: SW49.2, SW50.2, SW51.2, SW52.2, SW53.2, SW54.2; also elsewhere on the board
COL9: SW55.2, SW56.2, SW57.2, SW58.2, SW59.2, SW60.2; also elsewhere on the board
COL10: SW61.2, SW62.2, SW63.2, SW64.2, SW65.2, SW66.2; also elsewhere on the board
COL11: SW67.2, SW68.2, SW69.2, SW70.2, SW71.2, SW72.2; also elsewhere on the board
COL12: SW73.2, SW74.2, SW75.2, SW76.2; also elsewhere on the board
COL13: SW79.2, SW80.2, SW81.2, SW82.2, SW83.2, SW84.2; also elsewhere on the board
COL14: SW85.2, SW86.2, SW87.2, SW88.2, SW89.2, SW90.2; also elsewhere on the board
unnamed: D1.2 (A), SW1.1
unnamed: D2.2 (A), SW2.1
unnamed: D3.2 (A), SW3.1
unnamed: D4.2 (A), SW4.1
unnamed: D5.2 (A), SW5.1
unnamed: D6.2 (A), SW6.1
unnamed: D7.2 (A), SW7.1
unnamed: D8.2 (A), SW8.1
unnamed: D9.2 (A), SW9.1
unnamed: D10.2 (A), SW10.1
unnamed: D11.2 (A), SW11.1
unnamed: D12.2 (A), SW12.1
unnamed: D13.2 (A), SW13.1
unnamed: D14.2 (A), SW14.1
unnamed: D15.2 (A), SW15.1
unnamed: D16.2 (A), SW16.1
unnamed: D17.2 (A), SW17.1
unnamed: D18.2 (A), SW18.1
unnamed: D19.2 (A), SW19.1
unnamed: D20.2 (A), SW20.1
unnamed: D21.2 (A), SW21.1
unnamed: D22.2 (A), SW22.1
unnamed: D23.2 (A), SW23.1
unnamed: D25.2 (A), SW25.1
unnamed: D26.2 (A), SW26.1
unnamed: D27.2 (A), SW27.1
unnamed: D28.2 (A), SW28.1
unnamed: D29.2 (A), SW29.1
unnamed: D31.2 (A), SW31.1
unnamed: D32.2 (A), SW32.1
unnamed: D33.2 (A), SW33.1
unnamed: D34.2 (A), SW34.1
unnamed: D35.2 (A), SW35.1
unnamed: D36.2 (A), SW36.1
unnamed: D37.2 (A), SW37.1
unnamed: D38.2 (A), SW38.1
unnamed: D39.2 (A), SW39.1
unnamed: D40.2 (A), SW40.1
unnamed: D41.2 (A), SW41.1
unnamed: D43.2 (A), SW43.1
unnamed: D44.2 (A), SW44.1
unnamed: D45.2 (A), SW45.1
unnamed: D46.2 (A), SW46.1
unnamed: D47.2 (A), SW47.1
unnamed: D49.2 (A), SW49.1
unnamed: D50.2 (A), SW50.1
unnamed: D51.2 (A), SW51.1
unnamed: D52.2 (A), SW52.1
unnamed: D53.2 (A), SW53.1
unnamed: D54.2 (A), SW54.1
unnamed: D55.2 (A), SW55.1
unnamed: D56.2 (A), SW56.1
unnamed: D57.2 (A), SW57.1
unnamed: D58.2 (A), SW58.1
unnamed: D59.2 (A), SW59.1
unnamed: D60.2 (A), SW60.1
unnamed: D61.2 (A), SW61.1
unnamed: D62.2 (A), SW62.1
unnamed: D63.2 (A), SW63.1
unnamed: D64.2 (A), SW64.1
unnamed: D65.2 (A), SW65.1
unnamed: D66.2 (A), SW66.1
unnamed: D67.2 (A), SW67.1
unnamed: D68.2 (A), SW68.1
unnamed: D69.2 (A), SW69.1
unnamed: D70.2 (A), SW70.1
unnamed: D71.2 (A), SW71.1
unnamed: D72.2 (A), SW72.1
unnamed: D73.2 (A), SW73.1
unnamed: D74.2 (A), SW74.1
unnamed: D75.2 (A), SW75.1
unnamed: D76.2 (A), SW76.1
unnamed: D79.2 (A), SW79.1
unnamed: D80.2 (A), SW80.1
unnamed: D81.2 (A), SW81.1
unnamed: D82.2 (A), SW82.1
unnamed: D83.2 (A), SW83.1
unnamed: D84.2 (A), SW84.1
unnamed: D85.2 (A), SW85.1
unnamed: D86.2 (A), SW86.1
unnamed: D87.2 (A), SW87.1
unnamed: D88.2 (A), SW88.1
unnamed: D89.2 (A), SW89.1
unnamed: D90.2 (A), SW90.1
ROW0: D1.1 (K), D7.1 (K), D13.1 (K), D19.1 (K), D25.1 (K), D31.1 (K), D37.1 (K), D43.1 (K), D49.1 (K), D55.1 (K), D61.1 (K), D67.1 (K), D73.1 (K), D79.1 (K), D85.1 (K); also elsewhere on the board
ROW1: D2.1 (K), D8.1 (K), D14.1 (K), D20.1 (K), D26.1 (K), D32.1 (K), D38.1 (K), D44.1 (K), D50.1 (K), D56.1 (K), D62.1 (K), D68.1 (K), D74.1 (K), D80.1 (K), D86.1 (K); also elsewhere on the board
ROW2: D3.1 (K), D9.1 (K), D15.1 (K), D21.1 (K), D27.1 (K), D33.1 (K), D39.1 (K), D45.1 (K), D51.1 (K), D57.1 (K), D63.1 (K), D69.1 (K), D75.1 (K), D81.1 (K), D87.1 (K); also elsewhere on the board
ROW3: D4.1 (K), D10.1 (K), D16.1 (K), D22.1 (K), D28.1 (K), D34.1 (K), D40.1 (K), D46.1 (K), D52.1 (K), D58.1 (K), D64.1 (K), D70.1 (K), D76.1 (K), D82.1 (K), D88.1 (K); also elsewhere on the board
ROW4: D5.1 (K), D11.1 (K), D17.1 (K), D23.1 (K), D29.1 (K), D35.1 (K), D41.1 (K), D47.1 (K), D53.1 (K), D59.1 (K), D65.1 (K), D71.1 (K), D83.1 (K), D89.1 (K); also elsewhere on the board
ROW5: D6.1 (K), D12.1 (K), D18.1 (K), D36.1 (K), D54.1 (K), D60.1 (K), D66.1 (K), D72.1 (K), D84.1 (K), D90.1 (K); also elsewhere on the board

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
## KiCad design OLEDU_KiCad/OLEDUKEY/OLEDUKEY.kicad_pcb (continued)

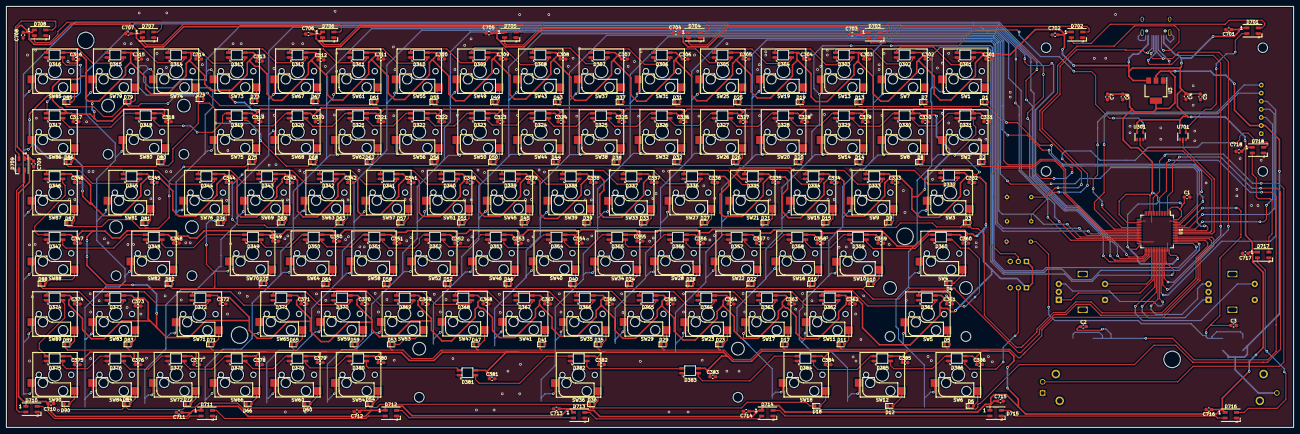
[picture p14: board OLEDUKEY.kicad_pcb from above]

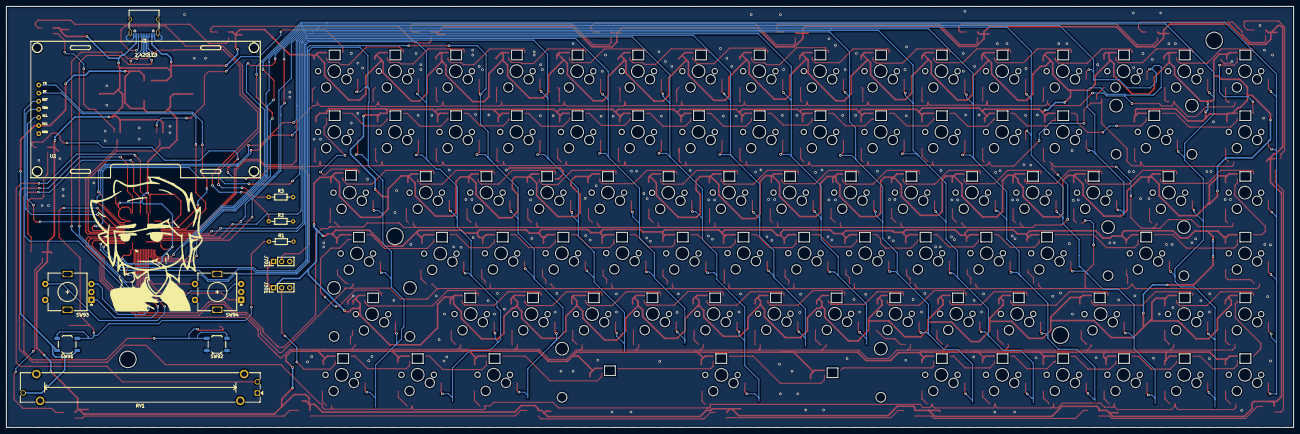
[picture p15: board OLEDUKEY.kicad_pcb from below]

Board: 2 copper layers, 403.9 x 132.1 mm, 400 parts (13 on the bottom side), 234 nets.

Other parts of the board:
G007: LOGO; jgfchj77eduardez

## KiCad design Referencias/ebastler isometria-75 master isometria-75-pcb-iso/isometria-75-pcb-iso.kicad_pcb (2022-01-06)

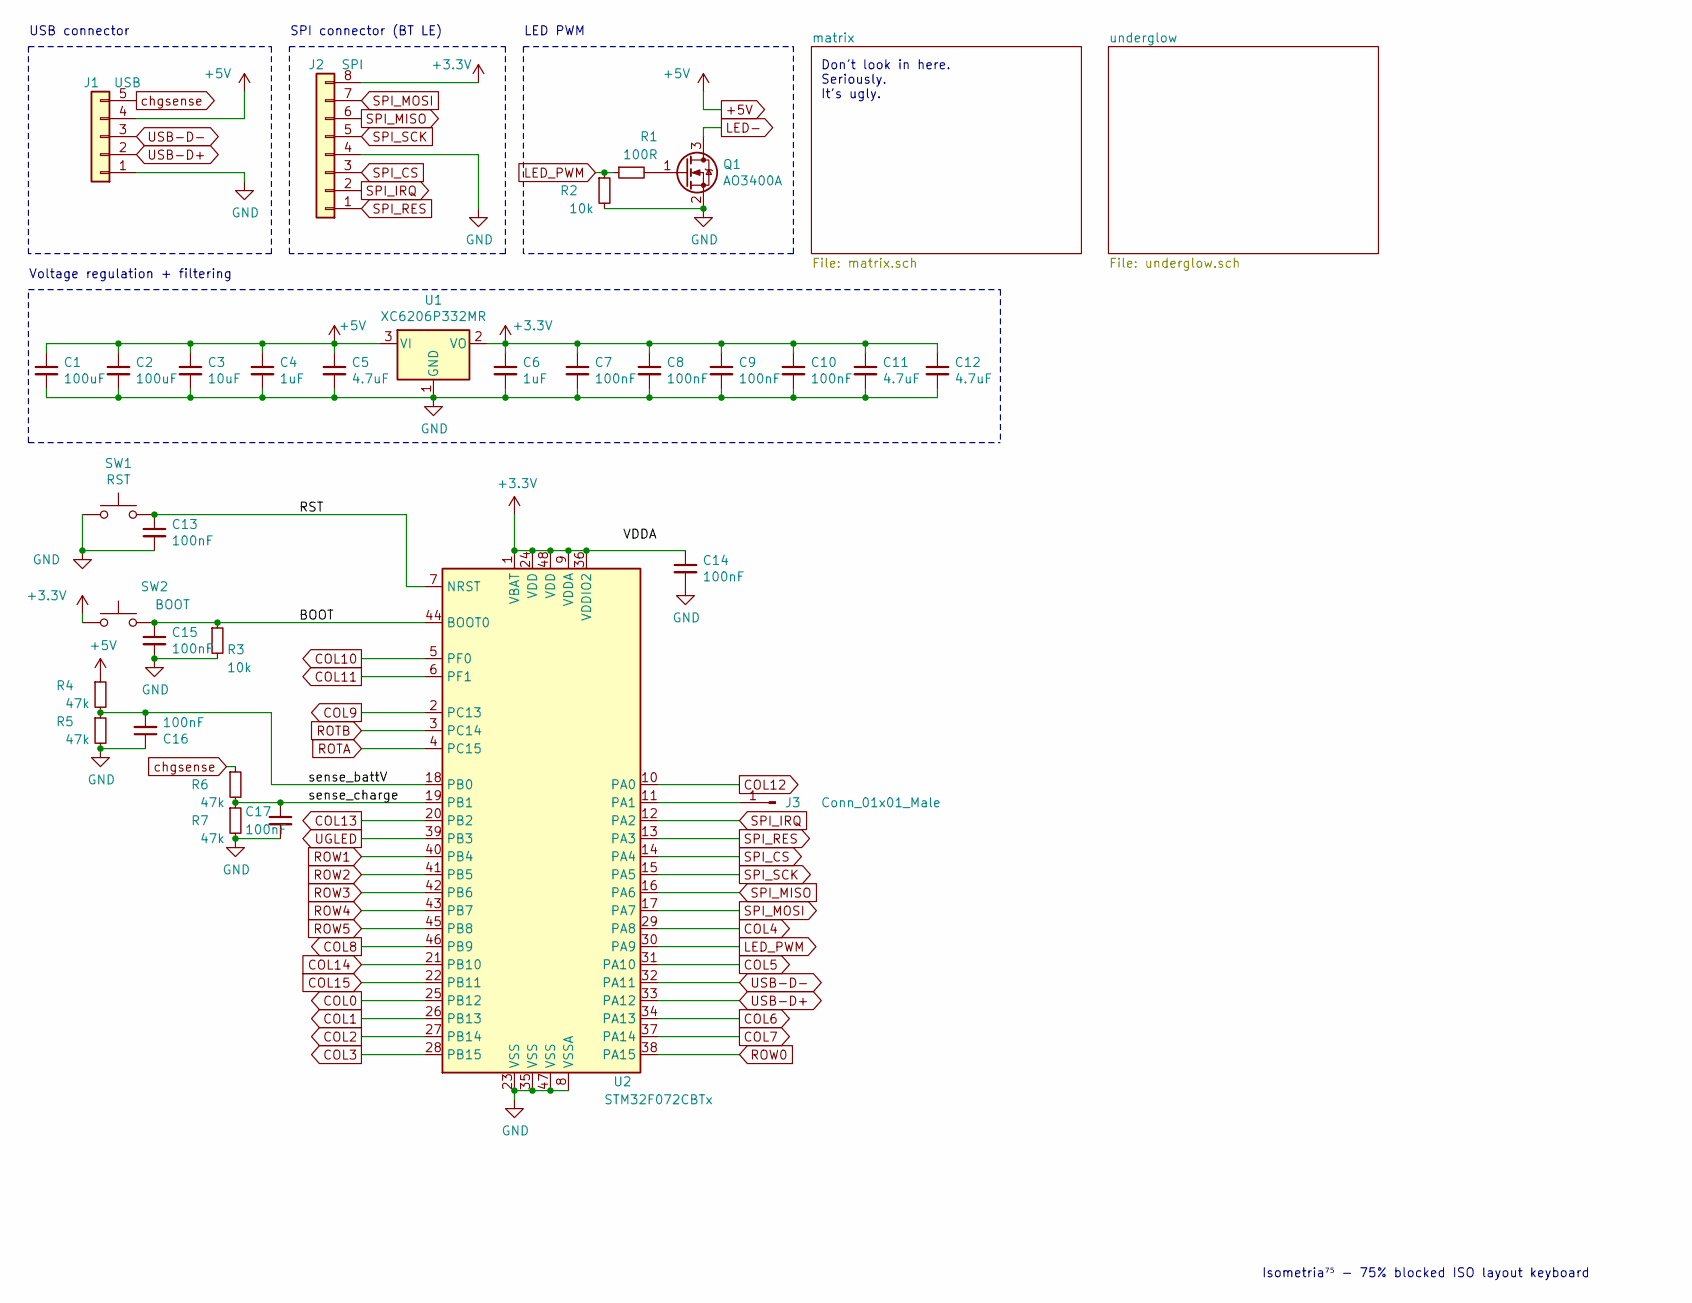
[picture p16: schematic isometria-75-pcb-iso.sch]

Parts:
C1, C2: 100uF; CP_EIA-3528-21_Kemet-B; LCSC C16133
C3: 10uF; CP_EIA-3216-18_Kemet-A; LCSC C7171
C4, C6: 1uF; C_0402_1005Metric; LCSC C52923
C5, C11, C12: 4.7uF; C_0402_1005Metric; LCSC C23733
C7, C8, C9, C10, C13, C14, C15, C16, C17: 100nF; C_0402_1005Metric; LCSC C1525
J1: USB; JST_SH_SM05B-SRSS-TB_1x05-1MP_P1.00mm_Horizontal
J2: SPI; JST_SH_SM08B-SRSS-TB_1x08-1MP_P1.00mm_Horizontal
J3: Conn_01x01_Male; PinHeader_1x01_P2.54mm_Vertical
Q1: AO3400A; SOT-23; LCSC C20917
R1: 100R; R_0402_1005Metric; LCSC C25076
R2, R3: 10k; R_0402_1005Metric; LCSC C25744
R4, R5, R6, R7: 47k; R_0402_1005Metric; LCSC C25792
SW1: RST; SW_SPST_SKQG_WithStem; LCSC C318886
SW2: BOOT; SW_SPST_SKQG_WithStem; LCSC C318886
U1: XC6206P332MR; SOT-23; LCSC C5446
U2: STM32F072CBTx; LQFP-48_7x7mm_P0.5mm; LCSC C81720

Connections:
+3V3: C6.1, C7.1, C8.1, C9.1, C10.1, C11.1, C12.1, C14.1, J2.8, SW2.1, U1.2 (VO), U2.1 (VBAT), U2.9 (VDDA), U2.24 (VDD), U2.36 (VDDIO2), U2.48 (VDD); also elsewhere on the board
+5V: C1.1, C2.1, C3.1, C4.1, C5.1, J1.4, R4.1, U1.3 (VI); also elsewhere on the board
/BOOT: C15.1, R3.1, SW2.2, U2.44 (BOOT0)
/RST: C13.1, SW1.2, U2.7 (NRST)
/sense_battV: C16.2, R4.2, R5.1, U2.18 (PB0)
/sense_charge: C17.1, R6.2, R7.1, U2.19 (PB1)
COL0: U2.25 (PB12); also elsewhere on the board
COL1: U2.26 (PB13); also elsewhere on the board
COL2: U2.27 (PB14); also elsewhere on the board
COL3: U2.28 (PB15); also elsewhere on the board
COL4: U2.29 (PA8); also elsewhere on the board
COL5: U2.31 (PA10); also elsewhere on the board
COL6: U2.34 (PA13); also elsewhere on the board
COL7: U2.37 (PA14); also elsewhere on the board
COL8: U2.46 (PB9); also elsewhere on the board
COL9: U2.2 (PC13); also elsewhere on the board
COL10: U2.5 (PF0); also elsewhere on the board
COL11: U2.6 (PF1); also elsewhere on the board
COL12: U2.10 (PA0); also elsewhere on the board
COL13: U2.20 (PB2); also elsewhere on the board
COL14: U2.21 (PB10); also elsewhere on the board
COL15: U2.22 (PB11); also elsewhere on the board
GND: C1.2, C2.2, C3.2, C4.2, C5.2, C6.2, C7.2, C8.2, C9.2, C10.2, C11.2, C12.2, C13.2, C14.2, C15.2, C16.1, C17.2, J1.1, J2.4, Q1.2 (S), R2.2, R3.2, R5.2, R7.2, SW1.1, U1.1 (GND), U2.8 (VSSA), U2.23 (VSS), U2.35 (VSS), U2.47 (VSS); also elsewhere on the board
LED-: Q1.3 (D); also elsewhere on the board
LED_PWM: R1.1, R2.1, U2.30 (PA9)
unnamed: J3.1, U2.11 (PA1)
unnamed: Q1.1 (G), R1.2
ROTA: U2.4 (PC15); also elsewhere on the board
ROTB: U2.3 (PC14); also elsewhere on the board
ROW0: U2.38 (PA15); also elsewhere on the board
ROW1: U2.40 (PB4); also elsewhere on the board
ROW2: U2.41 (PB5); also elsewhere on the board
ROW3: U2.42 (PB6); also elsewhere on the board
ROW4: U2.43 (PB7); also elsewhere on the board
ROW5: U2.45 (PB8); also elsewhere on the board
SPI_CS: J2.3, U2.14 (PA4)
SPI_IRQ: J2.2, U2.12 (PA2)
SPI_MISO: J2.6, U2.16 (PA6)
SPI_MOSI: J2.7, U2.17 (PA7)
SPI_RES: J2.1, U2.13 (PA3)
SPI_SCK: J2.5, U2.15 (PA5)
UGLED: U2.39 (PB3); also elsewhere on the board
USB-D+: J1.2, U2.33 (PA12)
USB-D-: J1.3, U2.32 (PA11)
chgsense: J1.5, R6.1

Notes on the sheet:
USB connector
SPI connector (BT LE)
Voltage regulation + filtering
LED PWM
Don't look in here. Seriously. It's ugly.
Isometria⁷⁵ - 75% blocked ISO layout keyboard

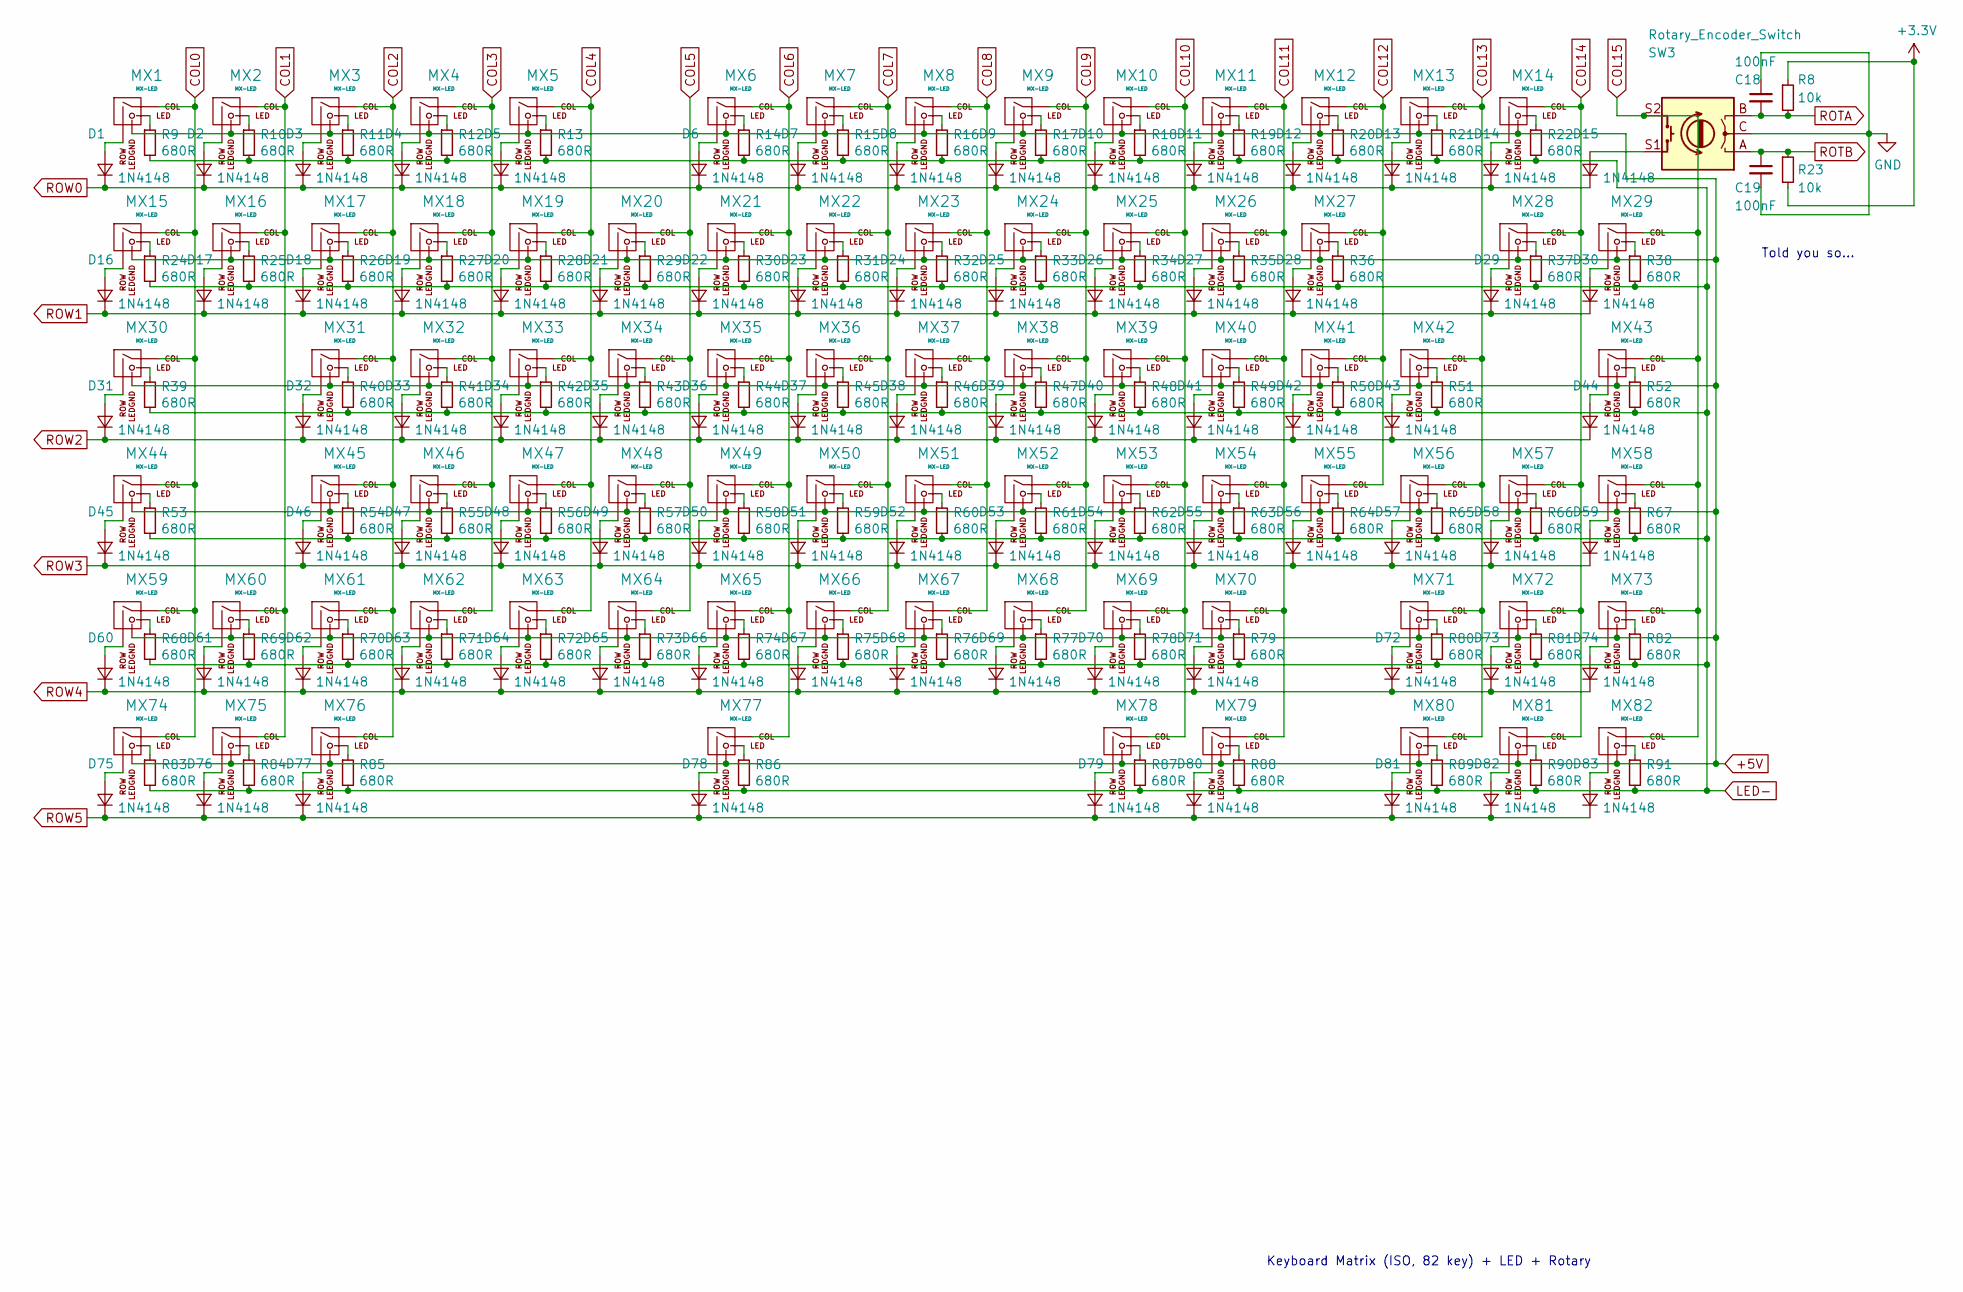
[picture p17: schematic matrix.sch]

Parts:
C18, C19: 100nF; C_0402_1005Metric; LCSC C1525
D1, D2, D3, D4, D5, D6, D7, D8, D9, D10, D11, D12, D13, D14, D15, D16, D17, D18, D19, D20, D21, D22, D23, D24, D25, D26, D27, D28, D29, D30, D31, D32, D33, D34, D35, D36, D37, D38, D39, D40, D41, D42, D43, D44, D45, D46, D47, D48, D49, D50, D51, D52, D53, D54, D55, D56, D57, D58, D59, D60, D61, D62, D63, D64, D65, D66, D67, D68, D69, D70, D71, D72, D73, D74, D75, D76, D77, D78, D79, D80, D81, D82, D83: 1N4148; D_SOD-323F; LCSC C2128
MX1, MX2, MX3, MX4, MX5, MX6, MX7, MX8, MX9, MX10, MX11, MX12, MX13, MX14, MX15, MX16, MX17, MX18, MX19, MX20, MX21, MX22, MX23, MX24, MX25, MX26, MX27, MX29, MX31, MX32, MX33, MX34, MX35, MX36, MX37, MX38, MX39, MX40, MX41, MX42, MX43, MX45, MX46, MX47, MX48, MX49, MX50, MX51, MX52, MX53, MX54, MX55, MX56, MX58, MX60, MX61, MX62, MX63, MX64, MX65, MX66, MX67, MX68, MX69, MX70, MX72, MX73, MX80, MX81, MX82: MX-LED; MXOnly-1U
MX28: MX-LED; MXOnly-2U-ReversedStabilizers
MX30, MX71, MX78: MX-LED; MXOnly-1.5U
MX44: MX-LED; MXOnly-1.75U
MX57: MX-LED; MXOnly-ISO
MX59, MX74, MX75, MX76, MX79: MX-LED; MXOnly-1.25U
MX77: MX-LED; MXOnly-6.25U
R8, R23: 10k; R_0402_1005Metric; LCSC C25744
R9, R10, R11, R12, R13, R14, R15, R16, R17, R18, R19, R20, R21, R22, R24, R25, R26, R27, R28, R29, R30, R31, R32, R33, R34, R35, R36, R37, R38, R39, R40, R41, R42, R43, R44, R45, R46, R47, R48, R49, R50, R51, R52, R53, R54, R55, R56, R57, R58, R59, R60, R61, R62, R63, R64, R65, R66, R67, R68, R69, R70, R71, R72, R73, R74, R75, R76, R77, R78, R79, R80, R81, R82, R83, R84, R85, R86, R87, R88, R89, R90, R91: 680R; R_0603_1608Metric; LCSC C23228
SW3: Rotary_Encoder_Switch; RotaryEncoder_Alps_EC11E-Switch_Vertical_H20mm

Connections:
+3V3: R8.1, R23.2; also elsewhere on the board
+5V: MX1.4 (LEDGND), MX2.4 (LEDGND), MX3.4 (LEDGND), MX4.4 (LEDGND), MX5.4 (LEDGND), MX6.4 (LEDGND), MX7.4 (LEDGND), MX8.4 (LEDGND), MX9.4 (LEDGND), MX10.4 (LEDGND), MX11.4 (LEDGND), MX12.4 (LEDGND), MX13.4 (LEDGND), MX14.4 (LEDGND), MX15.4 (LEDGND), MX16.4 (LEDGND), MX17.4 (LEDGND), MX18.4 (LEDGND), MX19.4 (LEDGND), MX20.4 (LEDGND), MX21.4 (LEDGND), MX22.4 (LEDGND), MX23.4 (LEDGND), MX24.4 (LEDGND), MX25.4 (LEDGND), MX26.4 (LEDGND), MX27.4 (LEDGND), MX28.4 (LEDGND), MX29.4 (LEDGND), MX30.4 (LEDGND), MX31.4 (LEDGND), MX32.4 (LEDGND), MX33.4 (LEDGND), MX34.4 (LEDGND), MX35.4 (LEDGND), MX36.4 (LEDGND), MX37.4 (LEDGND), MX38.4 (LEDGND), MX39.4 (LEDGND), MX40.4 (LEDGND), MX41.4 (LEDGND), MX42.4 (LEDGND), MX43.4 (LEDGND), MX44.4 (LEDGND), MX45.4 (LEDGND), MX46.4 (LEDGND), MX47.4 (LEDGND), MX48.4 (LEDGND), MX49.4 (LEDGND), MX50.4 (LEDGND), MX51.4 (LEDGND), MX52.4 (LEDGND), MX53.4 (LEDGND), MX54.4 (LEDGND), MX55.4 (LEDGND), MX56.4 (LEDGND), MX57.4 (LEDGND), MX58.4 (LEDGND), MX59.4 (LEDGND), MX60.4 (LEDGND), MX61.4 (LEDGND), MX62.4 (LEDGND), MX63.4 (LEDGND), MX64.4 (LEDGND), MX65.4 (LEDGND), MX66.4 (LEDGND), MX67.4 (LEDGND), MX68.4 (LEDGND), MX69.4 (LEDGND), MX70.4 (LEDGND), MX71.4 (LEDGND), MX72.4 (LEDGND), MX73.4 (LEDGND), MX74.4 (LEDGND), MX75.4 (LEDGND), MX76.4 (LEDGND), MX77.4 (LEDGND), MX78.4 (LEDGND), MX79.4 (LEDGND), MX80.4 (LEDGND), MX81.4 (LEDGND), MX82.4 (LEDGND); also elsewhere on the board
COL0: MX1.1 (COL), MX15.1 (COL), MX30.1 (COL), MX44.1 (COL), MX59.1 (COL), MX74.1 (COL); also elsewhere on the board
COL1: MX2.1 (COL), MX16.1 (COL), MX60.1 (COL), MX75.1 (COL); also elsewhere on the board
COL2: MX3.1 (COL), MX17.1 (COL), MX31.1 (COL), MX45.1 (COL), MX61.1 (COL), MX76.1 (COL); also elsewhere on the board
COL3: MX4.1 (COL), MX18.1 (COL), MX32.1 (COL), MX46.1 (COL), MX62.1 (COL); also elsewhere on the board
COL4: MX5.1 (COL), MX19.1 (COL), MX33.1 (COL), MX47.1 (COL), MX63.1 (COL); also elsewhere on the board
COL5: MX20.1 (COL), MX34.1 (COL), MX48.1 (COL), MX64.1 (COL); also elsewhere on the board
COL6: MX6.1 (COL), MX21.1 (COL), MX35.1 (COL), MX49.1 (COL), MX65.1 (COL), MX77.1 (COL); also elsewhere on the board
COL7: MX7.1 (COL), MX22.1 (COL), MX36.1 (COL), MX50.1 (COL), MX66.1 (COL); also elsewhere on the board
COL8: MX8.1 (COL), MX23.1 (COL), MX37.1 (COL), MX51.1 (COL), MX67.1 (COL); also elsewhere on the board
COL9: MX9.1 (COL), MX24.1 (COL), MX38.1 (COL), MX52.1 (COL), MX68.1 (COL); also elsewhere on the board
COL10: MX10.1 (COL), MX25.1 (COL), MX39.1 (COL), MX53.1 (COL), MX69.1 (COL), MX78.1 (COL); also elsewhere on the board
COL11: MX11.1 (COL), MX26.1 (COL), MX40.1 (COL), MX54.1 (COL), MX70.1 (COL), MX79.1 (COL); also elsewhere on the board
COL12: MX12.1 (COL), MX27.1 (COL), MX41.1 (COL), MX55.1 (COL); also elsewhere on the board
COL13: MX13.1 (COL), MX42.1 (COL), MX56.1 (COL), MX71.1 (COL), MX80.1 (COL); also elsewhere on the board
COL14: MX14.1 (COL), MX28.1 (COL), MX57.1 (COL), MX72.1 (COL), MX81.1 (COL); also elsewhere on the board
COL15: MX29.1 (COL), MX43.1 (COL), MX58.1 (COL), MX73.1 (COL), MX82.1 (COL), SW3.S2; also elsewhere on the board
GND: C18.1, C19.2, SW3.C; also elsewhere on the board
LED-: R9.2, R10.2, R11.2, R12.2, R13.2, R14.2, R15.2, R16.2, R17.2, R18.2, R19.2, R20.2, R21.2, R22.2, R24.2, R25.2, R26.2, R27.2, R28.2, R29.2, R30.2, R31.2, R32.2, R33.2, R34.2, R35.2, R36.2, R37.2, R38.2, R39.2, R40.2, R41.2, R42.2, R43.2, R44.2, R45.2, R46.2, R47.2, R48.2, R49.2, R50.2, R51.2, R52.2, R53.2, R54.2, R55.2, R56.2, R57.2, R58.2, R59.2, R60.2, R61.2, R62.2, R63.2, R64.2, R65.2, R66.2, R67.2, R68.2, R69.2, R70.2, R71.2, R72.2, R73.2, R74.2, R75.2, R76.2, R77.2, R78.2, R79.2, R80.2, R81.2, R82.2, R83.2, R84.2, R85.2, R86.2, R87.2, R88.2, R89.2, R90.2, R91.2; also elsewhere on the board
unnamed: D1.2 (A), MX1.2 (ROW)
unnamed: D2.2 (A), MX2.2 (ROW)
unnamed: D3.2 (A), MX3.2 (ROW)
unnamed: D4.2 (A), MX4.2 (ROW)
unnamed: D5.2 (A), MX5.2 (ROW)
unnamed: D6.2 (A), MX6.2 (ROW)
unnamed: D7.2 (A), MX7.2 (ROW)
unnamed: D8.2 (A), MX8.2 (ROW)
unnamed: D9.2 (A), MX9.2 (ROW)
unnamed: D10.2 (A), MX10.2 (ROW)
unnamed: D11.2 (A), MX11.2 (ROW)
unnamed: D12.2 (A), MX12.2 (ROW)
unnamed: D13.2 (A), MX13.2 (ROW)
unnamed: D14.2 (A), MX14.2 (ROW)
unnamed: D15.2 (A), SW3.S1
unnamed: D16.2 (A), MX15.2 (ROW)
unnamed: D17.2 (A), MX16.2 (ROW)
unnamed: D18.2 (A), MX17.2 (ROW)
unnamed: D19.2 (A), MX18.2 (ROW)
unnamed: D20.2 (A), MX19.2 (ROW)
unnamed: D21.2 (A), MX20.2 (ROW)
unnamed: D22.2 (A), MX21.2 (ROW)
unnamed: D23.2 (A), MX22.2 (ROW)
unnamed: D24.2 (A), MX23.2 (ROW)
unnamed: D25.2 (A), MX24.2 (ROW)
unnamed: D26.2 (A), MX25.2 (ROW)
unnamed: D27.2 (A), MX26.2 (ROW)
unnamed: D28.2 (A), MX27.2 (ROW)
unnamed: D29.2 (A), MX28.2 (ROW)
unnamed: D30.2 (A), MX29.2 (ROW)
unnamed: D31.2 (A), MX30.2 (ROW)
unnamed: D32.2 (A), MX31.2 (ROW)
unnamed: D33.2 (A), MX32.2 (ROW)
unnamed: D34.2 (A), MX33.2 (ROW)
unnamed: D35.2 (A), MX34.2 (ROW)
unnamed: D36.2 (A), MX35.2 (ROW)
unnamed: D37.2 (A), MX36.2 (ROW)
unnamed: D38.2 (A), MX37.2 (ROW)
unnamed: D39.2 (A), MX38.2 (ROW)
unnamed: D40.2 (A), MX39.2 (ROW)
unnamed: D41.2 (A), MX40.2 (ROW)
unnamed: D42.2 (A), MX41.2 (ROW)
unnamed: D43.2 (A), MX42.2 (ROW)
unnamed: D44.2 (A), MX43.2 (ROW)
unnamed: D45.2 (A), MX44.2 (ROW)
unnamed: D46.2 (A), MX45.2 (ROW)
unnamed: D47.2 (A), MX46.2 (ROW)
unnamed: D48.2 (A), MX47.2 (ROW)
unnamed: D49.2 (A), MX48.2 (ROW)
unnamed: D50.2 (A), MX49.2 (ROW)
unnamed: D51.2 (A), MX50.2 (ROW)
unnamed: D52.2 (A), MX51.2 (ROW)
unnamed: D53.2 (A), MX52.2 (ROW)
unnamed: D54.2 (A), MX53.2 (ROW)
unnamed: D55.2 (A), MX54.2 (ROW)
unnamed: D56.2 (A), MX55.2 (ROW)
unnamed: D57.2 (A), MX56.2 (ROW)
unnamed: D58.2 (A), MX57.2 (ROW)
unnamed: D59.2 (A), MX58.2 (ROW)
unnamed: D60.2 (A), MX59.2 (ROW)
unnamed: D61.2 (A), MX60.2 (ROW)
unnamed: D62.2 (A), MX61.2 (ROW)
unnamed: D63.2 (A), MX62.2 (ROW)
unnamed: D64.2 (A), MX63.2 (ROW)
unnamed: D65.2 (A), MX64.2 (ROW)
unnamed: D66.2 (A), MX65.2 (ROW)
unnamed: D67.2 (A), MX66.2 (ROW)
unnamed: D68.2 (A), MX67.2 (ROW)
unnamed: D69.2 (A), MX68.2 (ROW)
unnamed: D70.2 (A), MX69.2 (ROW)
unnamed: D71.2 (A), MX70.2 (ROW)
unnamed: D72.2 (A), MX71.2 (ROW)
unnamed: D73.2 (A), MX72.2 (ROW)
unnamed: D74.2 (A), MX73.2 (ROW)
unnamed: D75.2 (A), MX74.2 (ROW)
unnamed: D76.2 (A), MX75.2 (ROW)
unnamed: D77.2 (A), MX76.2 (ROW)
unnamed: D78.2 (A), MX77.2 (ROW)
unnamed: D79.2 (A), MX78.2 (ROW)
unnamed: D80.2 (A), MX79.2 (ROW)
unnamed: D81.2 (A), MX80.2 (ROW)
unnamed: D82.2 (A), MX81.2 (ROW)
unnamed: D83.2 (A), MX82.2 (ROW)
unnamed: MX1.3 (LED), R9.1
unnamed: MX2.3 (LED), R10.1
unnamed: MX3.3 (LED), R11.1
unnamed: MX4.3 (LED), R12.1
unnamed: MX5.3 (LED), R13.1
unnamed: MX6.3 (LED), R14.1
unnamed: MX7.3 (LED), R15.1
unnamed: MX8.3 (LED), R16.1
unnamed: MX9.3 (LED), R17.1
unnamed: MX10.3 (LED), R18.1
unnamed: MX11.3 (LED), R19.1
unnamed: MX12.3 (LED), R20.1
unnamed: MX13.3 (LED), R21.1
unnamed: MX14.3 (LED), R22.1
unnamed: MX15.3 (LED), R24.1
unnamed: MX16.3 (LED), R25.1
unnamed: MX17.3 (LED), R26.1
unnamed: MX18.3 (LED), R27.1
unnamed: MX19.3 (LED), R28.1
unnamed: MX20.3 (LED), R29.1
unnamed: MX21.3 (LED), R30.1
unnamed: MX22.3 (LED), R31.1
unnamed: MX23.3 (LED), R32.1
unnamed: MX24.3 (LED), R33.1
unnamed: MX25.3 (LED), R34.1
unnamed: MX26.3 (LED), R35.1
unnamed: MX27.3 (LED), R36.1
unnamed: MX28.3 (LED), R37.1
unnamed: MX29.3 (LED), R38.1
unnamed: MX30.3 (LED), R39.1
unnamed: MX31.3 (LED), R40.1
unnamed: MX32.3 (LED), R41.1
unnamed: MX33.3 (LED), R42.1
unnamed: MX34.3 (LED), R43.1
unnamed: MX35.3 (LED), R44.1
unnamed: MX36.3 (LED), R45.1
unnamed: MX37.3 (LED), R46.1
unnamed: MX38.3 (LED), R47.1
unnamed: MX39.3 (LED), R48.1
unnamed: MX40.3 (LED), R49.1
unnamed: MX41.3 (LED), R50.1
unnamed: MX42.3 (LED), R51.1
unnamed: MX43.3 (LED), R52.1
unnamed: MX44.3 (LED), R53.1
unnamed: MX45.3 (LED), R54.1
unnamed: MX46.3 (LED), R55.1
unnamed: MX47.3 (LED), R56.1
unnamed: MX48.3 (LED), R57.1
unnamed: MX49.3 (LED), R58.1
unnamed: MX50.3 (LED), R59.1
unnamed: MX51.3 (LED), R60.1
unnamed: MX52.3 (LED), R61.1
unnamed: MX53.3 (LED), R62.1
unnamed: MX54.3 (LED), R63.1
unnamed: MX55.3 (LED), R64.1
unnamed: MX56.3 (LED), R65.1
unnamed: MX57.3 (LED), R66.1
unnamed: MX58.3 (LED), R67.1
unnamed: MX59.3 (LED), R68.1
unnamed: MX60.3 (LED), R69.1
unnamed: MX61.3 (LED), R70.1
unnamed: MX62.3 (LED), R71.1
unnamed: MX63.3 (LED), R72.1
unnamed: MX64.3 (LED), R73.1
unnamed: MX65.3 (LED), R74.1
unnamed: MX66.3 (LED), R75.1
unnamed: MX67.3 (LED), R76.1
unnamed: MX68.3 (LED), R77.1
unnamed: MX69.3 (LED), R78.1
unnamed: MX70.3 (LED), R79.1
unnamed: MX71.3 (LED), R80.1
unnamed: MX72.3 (LED), R81.1
unnamed: MX73.3 (LED), R82.1
unnamed: MX74.3 (LED), R83.1
unnamed: MX75.3 (LED), R84.1
unnamed: MX76.3 (LED), R85.1
unnamed: MX77.3 (LED), R86.1
unnamed: MX78.3 (LED), R87.1
unnamed: MX79.3 (LED), R88.1
unnamed: MX80.3 (LED), R89.1
unnamed: MX81.3 (LED), R90.1
unnamed: MX82.3 (LED), R91.1
ROTA: C18.2, R8.2, SW3.B; also elsewhere on the board
ROTB: C19.1, R23.1, SW3.A; also elsewhere on the board
ROW0: D1.1 (K), D2.1 (K), D3.1 (K), D4.1 (K), D5.1 (K), D6.1 (K), D7.1 (K), D8.1 (K), D9.1 (K), D10.1 (K), D11.1 (K), D12.1 (K), D13.1 (K), D14.1 (K), D15.1 (K); also elsewhere on the board
ROW1: D16.1 (K), D17.1 (K), D18.1 (K), D19.1 (K), D20.1 (K), D21.1 (K), D22.1 (K), D23.1 (K), D24.1 (K), D25.1 (K), D26.1 (K), D27.1 (K), D28.1 (K), D29.1 (K), D30.1 (K); also elsewhere on the board
ROW2: D31.1 (K), D32.1 (K), D33.1 (K), D34.1 (K), D35.1 (K), D36.1 (K), D37.1 (K), D38.1 (K), D39.1 (K), D40.1 (K), D41.1 (K), D42.1 (K), D43.1 (K), D44.1 (K); also elsewhere on the board
ROW3: D45.1 (K), D46.1 (K), D47.1 (K), D48.1 (K), D49.1 (K), D50.1 (K), D51.1 (K), D52.1 (K), D53.1 (K), D54.1 (K), D55.1 (K), D56.1 (K), D57.1 (K), D58.1 (K), D59.1 (K); also elsewhere on the board
ROW4: D60.1 (K), D61.1 (K), D62.1 (K), D63.1 (K), D64.1 (K), D65.1 (K), D66.1 (K), D67.1 (K), D68.1 (K), D69.1 (K), D70.1 (K), D71.1 (K), D72.1 (K), D73.1 (K), D74.1 (K); also elsewhere on the board
ROW5: D75.1 (K), D76.1 (K), D77.1 (K), D78.1 (K), D79.1 (K), D80.1 (K), D81.1 (K), D82.1 (K), D83.1 (K); also elsewhere on the board

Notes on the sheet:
Told you so...
Keyboard Matrix (ISO, 82 key) + LED + Rotary

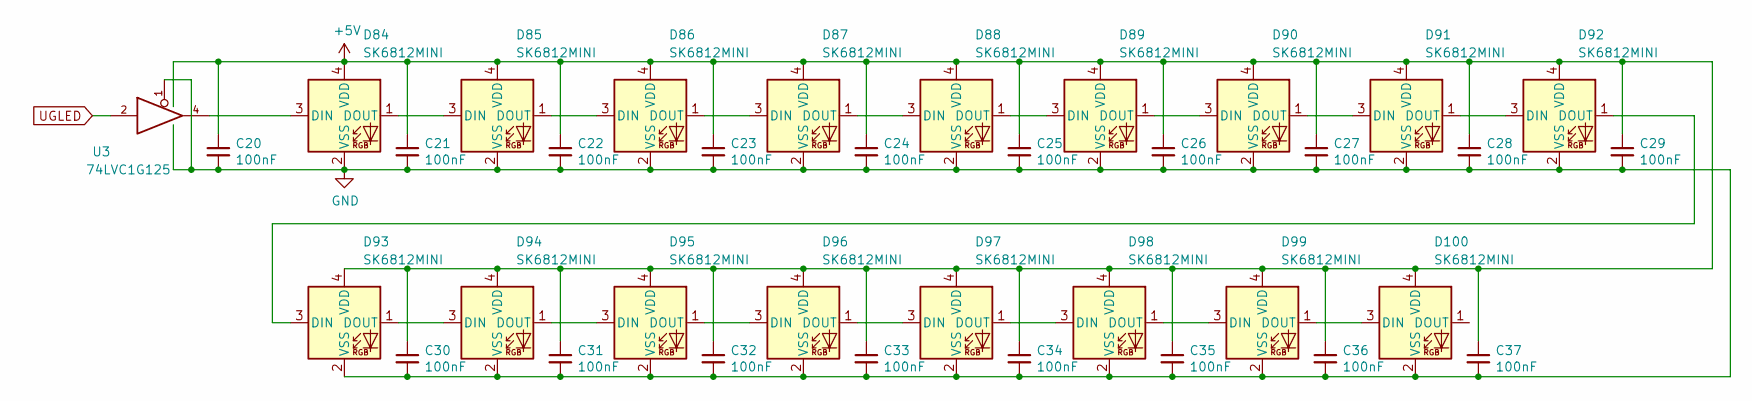
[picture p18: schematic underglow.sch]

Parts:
C20, C21, C22, C23, C24, C25, C26, C27, C28, C29, C30, C31, C32, C33, C34, C35, C36, C37: 100nF; C_0402_1005Metric; LCSC C1525
D84, D85, D86, D87, D88, D89, D90, D91, D92, D93, D94, D95, D96, D97, D98, D99, D100: SK6812MINI; LED_SK6812MINI_PLCC4_3.5x3.5mm_P1.75mm
U3: 74LVC1G125; SOT-23-5; LCSC C23654

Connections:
+5V: C20.1, C21.1, C22.1, C23.1, C24.1, C25.1, C26.1, C27.1, C28.1, C29.1, C30.1, C31.1, C32.1, C33.1, C34.1, C35.1, C36.1, C37.1, D84.4 (VDD), D85.4 (VDD), D86.4 (VDD), D87.4 (VDD), D88.4 (VDD), D89.4 (VDD), D90.4 (VDD), D91.4 (VDD), D92.4 (VDD), D93.4 (VDD), D94.4 (VDD), D95.4 (VDD), D96.4 (VDD), D97.4 (VDD), D98.4 (VDD), D99.4 (VDD), D100.4 (VDD), U3.5 (VCC); also elsewhere on the board
GND: C20.2, C21.2, C22.2, C23.2, C24.2, C25.2, C26.2, C27.2, C28.2, C29.2, C30.2, C31.2, C32.2, C33.2, C34.2, C35.2, C36.2, C37.2, D84.2 (VSS), D85.2 (VSS), D86.2 (VSS), D87.2 (VSS), D88.2 (VSS), D89.2 (VSS), D90.2 (VSS), D91.2 (VSS), D92.2 (VSS), D93.2 (VSS), D94.2 (VSS), D95.2 (VSS), D96.2 (VSS), D97.2 (VSS), D98.2 (VSS), D99.2 (VSS), D100.2 (VSS), U3.1, U3.3 (GND); also elsewhere on the board
unnamed: D84.1 (DOUT), D85.3 (DIN)
unnamed: D84.3 (DIN), U3.4
unnamed: D85.1 (DOUT), D86.3 (DIN)
unnamed: D86.1 (DOUT), D87.3 (DIN)
unnamed: D87.1 (DOUT), D88.3 (DIN)
unnamed: D88.1 (DOUT), D89.3 (DIN)
unnamed: D89.1 (DOUT), D90.3 (DIN)
unnamed: D90.1 (DOUT), D91.3 (DIN)
unnamed: D91.1 (DOUT), D92.3 (DIN)
unnamed: D92.1 (DOUT), D93.3 (DIN)
unnamed: D93.1 (DOUT), D94.3 (DIN)
unnamed: D94.1 (DOUT), D95.3 (DIN)
unnamed: D95.1 (DOUT), D96.3 (DIN)
unnamed: D96.1 (DOUT), D97.3 (DIN)
unnamed: D97.1 (DOUT), D98.3 (DIN)
unnamed: D98.1 (DOUT), D99.3 (DIN)
unnamed: D99.1 (DOUT), D100.3 (DIN)
UGLED: U3.2; also elsewhere on the board

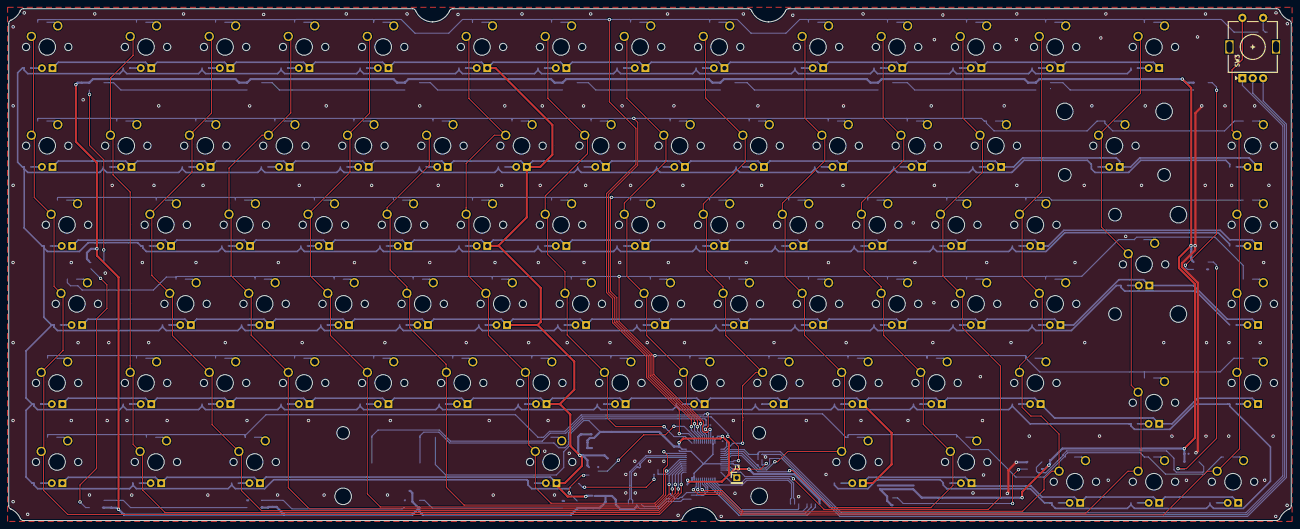
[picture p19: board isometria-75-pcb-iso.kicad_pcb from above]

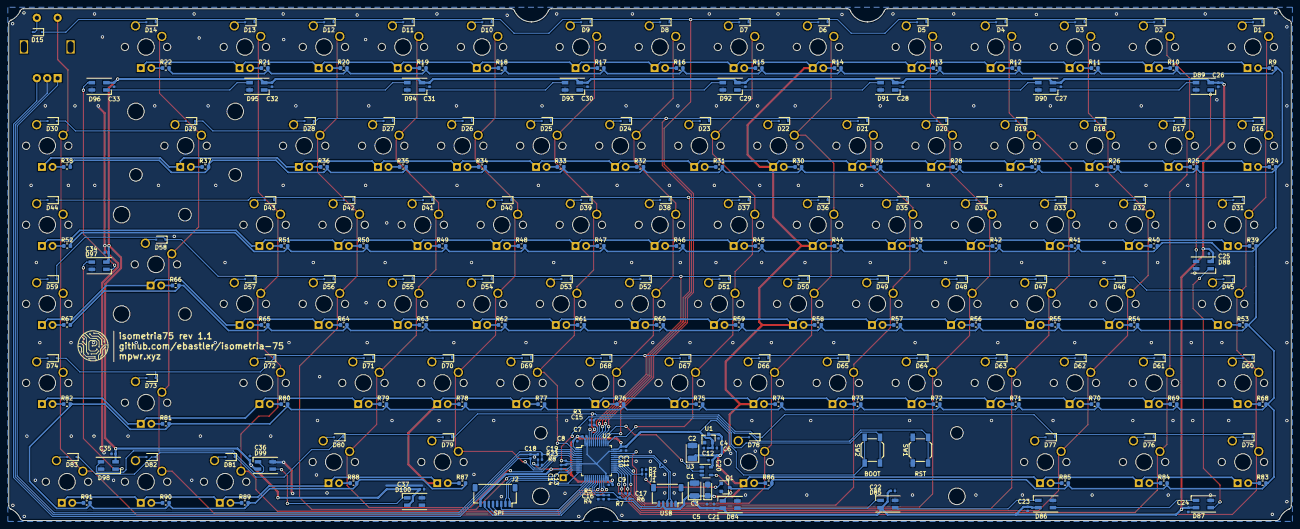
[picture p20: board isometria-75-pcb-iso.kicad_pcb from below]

Board: 2 copper layers, 308.3 x 123.0 mm, 320 parts (236 on the bottom side), 227 nets.

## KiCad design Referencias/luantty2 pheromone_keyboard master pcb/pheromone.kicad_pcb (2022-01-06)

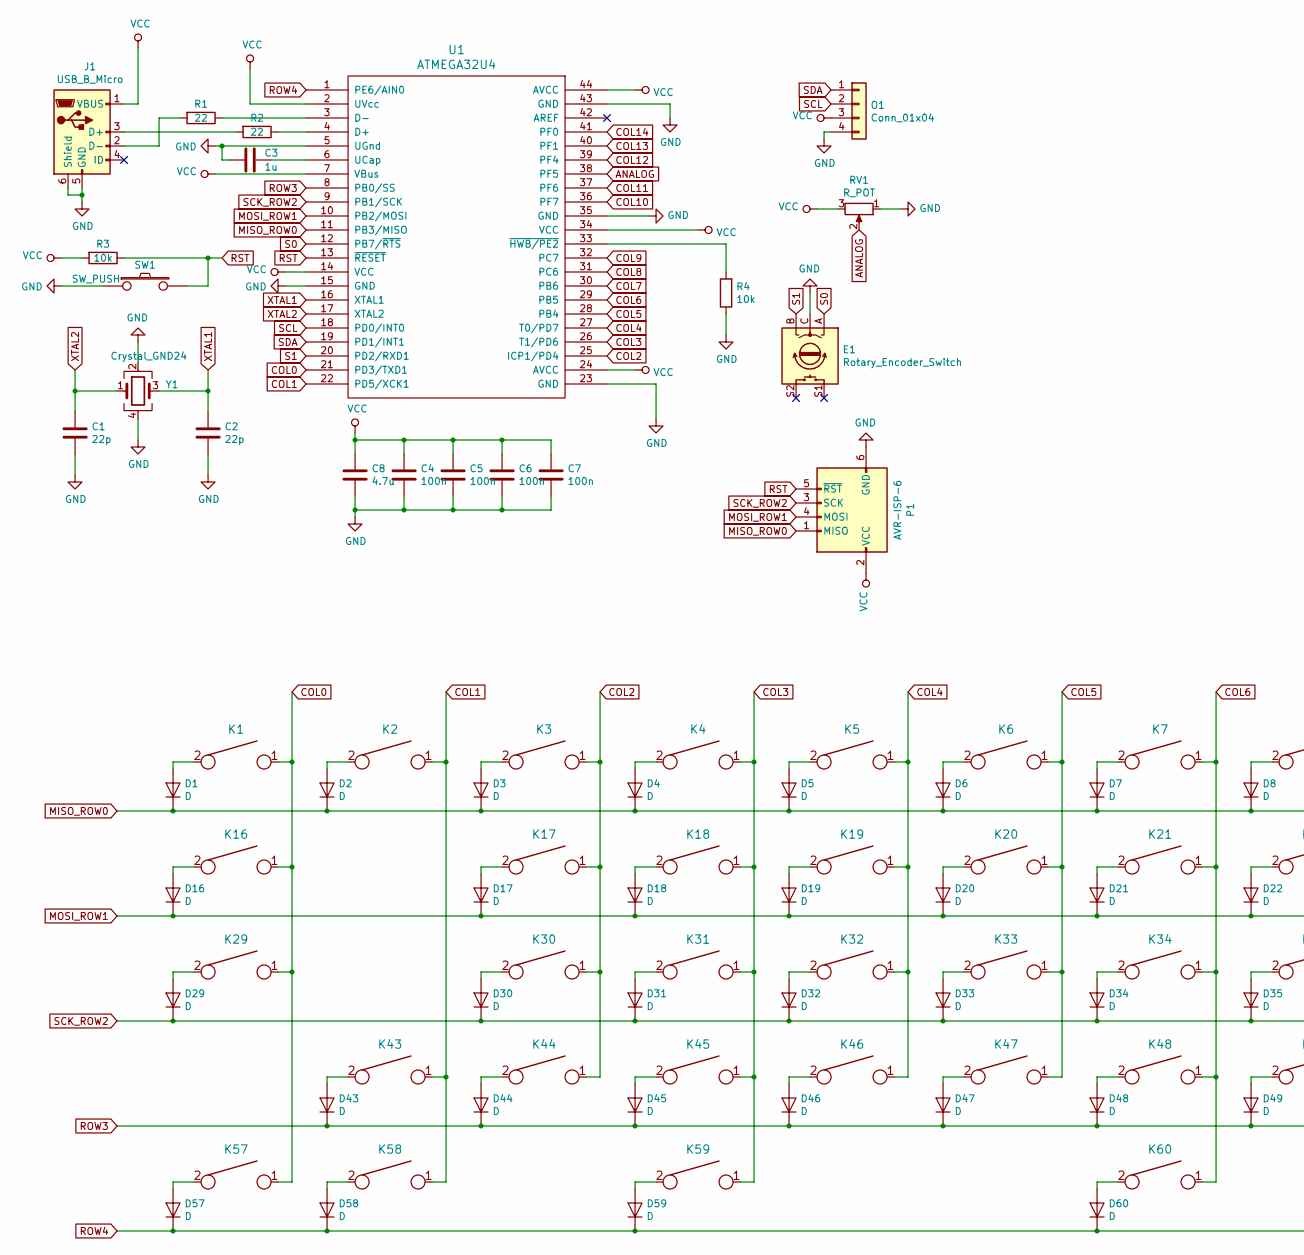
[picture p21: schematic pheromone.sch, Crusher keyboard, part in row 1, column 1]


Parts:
C1, C2: 22p; C_0805_2012Metric
C3: 1u; C_0805_2012Metric
C4, C5, C6, C7: 100n; C_0805_2012Metric
C8: 4.7u; C_0805_2012Metric
D1, D2, D3, D4, D5, D6, D7, D8, D9, D10, D11, D12, D13, D14, D15, D16, D17, D18, D19, D20, D21, D22, D23, D24, D25, D26, D27, D28, D29, D30, D31, D32, D33, D34, D35, D36, D37, D38, D39, D40, D41, D42, D43, D44, D45, D46, D47, D48, D49, D50, D51, D52, D53, D54, D55, D56, D57, D58, D59, D60, D61, D62, D63: D; D_SOD-123
E1: Rotary_Encoder_Switch; RotaryEncoder_Alps_EC11E-Switch_Vertical_H20mm
J1: USB_B_Micro; USB_Micro-B_Molex-105017-0001
K1, K2, K3, K4, K5, K6, K7, K8, K9, K10, K11, K12, K13, K14, K15, K17, K18, K19, K20, K21, K22, K23, K24, K25, K26, K27, K28, K30, K31, K32, K33, K34, K35, K36, K37, K38, K39, K40, K41, K44, K45, K46, K47, K48, K49, K50, K51, K52, K53, K54, K55, K56, K61, K62, K63: KEYSW; MXOnly-1U-Hotswap
K16: KEYSW; MXOnly-1.5U-Hotswap
K29: KEYSW; MXOnly-1.75U-Hotswap
K42: KEYSW; MXOnly-ISO-Hotswap
K43: KEYSW; MXOnly-2U-Hotswap-ReversedStabilizers
K57, K58, K59: KEYSW; MXOnly-1.25U-Hotswap
K60: KEYSW; MXOnly-6.25U-Hotswap-ReversedStabilizers
O1: Conn_01x04; 0.91_SSD1306_OLED
P1: AVR-ISP-6; PinHeader_2x03_P2.54mm_Vertical
R1, R2: 22; R_0805_2012Metric
R3, R4: 10k; R_0805_2012Metric
RV1: R_POT; potentiometer_slider_45mm
SW1: SW_PUSH; SW_DIP_SPSTx01_Slide_6.7x4.1mm_W6.73mm_P2.54mm_LowProfile_J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
U1: ATMEGA32U4; TQFP-44_10x10mm_Pitch0.8mm
Y1: Crystal_GND24; Crystal_SMD_3225-4Pin_3.2x2.5mm

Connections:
ANALOG: RV1.2, U1.38 (PF5)
COL0: K1.1, K16.1, K29.1, K57.1, U1.21 (PD3/TXD1)
COL1: K2.1, K43.1, K58.1, U1.22 (PD5/XCK1)
COL2: K3.1, K17.1, K30.1, K44.1, U1.25 (ICP1/PD4)
COL3: K4.1, K18.1, K31.1, K45.1, K59.1, U1.26 (T1/PD6)
COL4: K5.1, K19.1, K32.1, K46.1, U1.27 (T0/PD7)
COL5: K6.1, K20.1, K33.1, K47.1, U1.28 (PB4)
COL6: K7.1, K21.1, K34.1, K48.1, K60.1, U1.29 (PB5)
COL7: K8.1, K22.1, K35.1, K49.1, U1.30 (PB6)
COL8: K9.1, K23.1, K36.1, K50.1, U1.31 (PC6)
COL9: K10.1, K24.1, K37.1, K51.1, U1.32 (PC7)
COL10: K11.1, K25.1, K38.1, K52.1, U1.36 (PF7)
COL11: K12.1, K26.1, K39.1, K53.1, U1.37 (PF6)
COL12: K13.1, K27.1, K40.1, K54.1, K61.1, U1.39 (PF4)
COL13: K14.1, K28.1, K41.1, K55.1, K62.1, U1.40 (PF1)
COL14: K15.1, K42.1, K56.1, K63.1, U1.41 (PF0)
GND: C1.1, C2.1, C3.1, C4.1, C5.1, C6.1, C7.1, C8.1, E1.C, J1.5 (GND), J1.6 (Shield), O1.4, P1.6 (GND), R4.1, RV1.1, SW1.1, U1.5 (UGnd), U1.15 (GND), U1.23 (GND), U1.35 (GND), U1.43 (GND), Y1.2, Y1.4
MISO_ROW0: D1.1 (K), D2.1 (K), D3.1 (K), D4.1 (K), D5.1 (K), D6.1 (K), D7.1 (K), D8.1 (K), D9.1 (K), D10.1 (K), D11.1 (K), D12.1 (K), D13.1 (K), D14.1 (K), D15.1 (K), P1.1 (MISO), U1.11 (PB3/MISO)
MOSI_ROW1: D16.1 (K), D17.1 (K), D18.1 (K), D19.1 (K), D20.1 (K), D21.1 (K), D22.1 (K), D23.1 (K), D24.1 (K), D25.1 (K), D26.1 (K), D27.1 (K), D28.1 (K), P1.4 (MOSI), U1.10 (PB2/MOSI)
unnamed: C3.2, U1.6 (UCap)
unnamed: D1.2 (A), K1.2
unnamed: D2.2 (A), K2.2
unnamed: D3.2 (A), K3.2
unnamed: D4.2 (A), K4.2
unnamed: D5.2 (A), K5.2
unnamed: D6.2 (A), K6.2
unnamed: D7.2 (A), K7.2
unnamed: D8.2 (A), K8.2
unnamed: D9.2 (A), K9.2
unnamed: D10.2 (A), K10.2
unnamed: D11.2 (A), K11.2
unnamed: D12.2 (A), K12.2
unnamed: D13.2 (A), K13.2
unnamed: D14.2 (A), K14.2
unnamed: D15.2 (A), K15.2
unnamed: D16.2 (A), K16.2
unnamed: D17.2 (A), K17.2
unnamed: D18.2 (A), K18.2
unnamed: D19.2 (A), K19.2
unnamed: D20.2 (A), K20.2
unnamed: D21.2 (A), K21.2
unnamed: D22.2 (A), K22.2
unnamed: D23.2 (A), K23.2
unnamed: D24.2 (A), K24.2
unnamed: D25.2 (A), K25.2
unnamed: D26.2 (A), K26.2
unnamed: D27.2 (A), K27.2
unnamed: D28.2 (A), K28.2
unnamed: D29.2 (A), K29.2
unnamed: D30.2 (A), K30.2
unnamed: D31.2 (A), K31.2
unnamed: D32.2 (A), K32.2
unnamed: D33.2 (A), K33.2
unnamed: D34.2 (A), K34.2
unnamed: D35.2 (A), K35.2
unnamed: D36.2 (A), K36.2
unnamed: D37.2 (A), K37.2
unnamed: D38.2 (A), K38.2
unnamed: D39.2 (A), K39.2
unnamed: D40.2 (A), K40.2
unnamed: D41.2 (A), K41.2
unnamed: D42.2 (A), K42.2
unnamed: D43.2 (A), K43.2
unnamed: D44.2 (A), K44.2
unnamed: D45.2 (A), K45.2
unnamed: D46.2 (A), K46.2
unnamed: D47.2 (A), K47.2
unnamed: D48.2 (A), K48.2
unnamed: D49.2 (A), K49.2
unnamed: D50.2 (A), K50.2
unnamed: D51.2 (A), K51.2
unnamed: D52.2 (A), K52.2
unnamed: D53.2 (A), K53.2
unnamed: D54.2 (A), K54.2
unnamed: D55.2 (A), K55.2
unnamed: D56.2 (A), K56.2
unnamed: D57.2 (A), K57.2
unnamed: D58.2 (A), K58.2
unnamed: D59.2 (A), K59.2
unnamed: D60.2 (A), K60.2
unnamed: D61.2 (A), K61.2
unnamed: D62.2 (A), K62.2
unnamed: D63.2 (A), K63.2
unnamed: J1.2 (D-), R1.2
unnamed: J1.3 (D+), R2.2
unnamed: R1.1, U1.3 (D-)
unnamed: R2.1, U1.4 (D+)
unnamed: R4.2, U1.33 (~HWB/PE2)
ROW3: D43.1 (K), D44.1 (K), D45.1 (K), D46.1 (K), D47.1 (K), D48.1 (K), D49.1 (K), D50.1 (K), D51.1 (K), D52.1 (K), D53.1 (K), D54.1 (K), D55.1 (K), D56.1 (K), U1.8 (PB0/SS)
ROW4: D57.1 (K), D58.1 (K), D59.1 (K), D60.1 (K), D61.1 (K), D62.1 (K), D63.1 (K), U1.1 (PE6/AIN0)
RST: P1.5 (~RST), R3.1, SW1.2, U1.13 (~RESET)
S0: E1.A, U1.12 (PB7/~RTS)
S1: E1.B, U1.20 (PD2/RXD1)
SCK_ROW2: D29.1 (K), D30.1 (K), D31.1 (K), D32.1 (K), D33.1 (K), D34.1 (K), D35.1 (K), D36.1 (K), D37.1 (K), D38.1 (K), D39.1 (K), D40.1 (K), D41.1 (K), D42.1 (K), P1.3 (SCK), U1.9 (PB1/SCK)
SCL: O1.2, U1.18 (PD0/INT0)
SDA: O1.1, U1.19 (PD1/INT1)
VCC: C4.2, C5.2, C6.2, C7.2, C8.2, J1.1 (VBUS), O1.3, P1.2 (VCC), R3.2, RV1.3, U1.2 (UVcc), U1.7 (VBus), U1.14 (VCC), U1.24 (AVCC), U1.34 (VCC), U1.44 (AVCC)
XTAL1: C2.2, U1.16 (XTAL1), Y1.3
XTAL2: C1.2, U1.17 (XTAL2), Y1.1



Board: 2 copper layers, 304.0 x 99.0 mm, 152 parts (80 on the bottom side), 99 nets.

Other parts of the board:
[SCREW]: MountingHole_2.2mm_M2
[SCREW]#2, [SCREW]#3, [SCREW]#4, [SCREW]#5, [SCREW]#6: MountingHole_2.2mm_M2

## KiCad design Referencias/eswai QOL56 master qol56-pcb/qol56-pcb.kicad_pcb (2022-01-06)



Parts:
D1, D2, D3, D4, D5, D6, D7, D8, D9, D10, D11, D12, D13, D14, D15, D16, D17, D18, D19, D20, D21, D22, D23, D24, D25, D26, D27, D28, D29, D30, D31, D32, D33, D34, D35, D36, D37, D38, D39, D40, D41, D42, D43, D44, D45, D46, D47, D48, D49, D50, D51, D52, D53, D54, D55, D56: D; Diode-dual
H1, H2, H3, H4, H5, H6, H7, H8: MountingHole_Pad; MountingHole_4mm_Pad
J1: Conn_01x03; StripLED_rev
L1, L2, L3, L4, L5, L6, L7, L8, L9, L10, L11, L12, L13, L14, L15, L16, L17, L18, L19, L20, L21, L22, L23, L24, L25, L26, L27, L28, L29, L30, L31, L32, L33, L34, L35, L36, L37, L38, L39, L40, L41, L42, L43, L44, L45, L46, L47, L48, L49, L50, L51, L52, L53, L54, L55, L56: SK6812MINI; SK6812MINI_rev
SW1, SW2: SW_PUSH; MX_PCB_100H
SW3, SW4, SW5, SW6, SW7, SW8, SW9, SW10, SW11, SW12, SW13, SW14, SW15, SW16, SW17, SW18, SW19, SW20, SW21, SW22, SW23, SW24, SW25, SW26, SW27, SW28, SW29, SW30, SW31, SW32, SW33, SW34, SW35, SW36, SW37, SW38, SW39, SW40, SW41, SW42, SW43, SW44, SW45, SW46, SW47, SW48, SW49, SW50, SW51, SW52, SW53, SW54, SW55, SW56: SW_PUSH; CherryMX_Hotswap
SW57: SW_PUSH; SMD 2Pin 3X4MM Tactile Tact Push Button
U1: ProMicro; ArduinoProMicro

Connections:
GND: H1.1, H2.1, H3.1, H4.1, H5.1, H6.1, H7.1, H8.1, J1.3, L1.2 (VSS), L2.2 (VSS), L3.2 (VSS), L4.2 (VSS), L5.2 (VSS), L6.2 (VSS), L7.2 (VSS), L8.2 (VSS), L9.2 (VSS), L10.2 (VSS), L11.2 (VSS), L12.2 (VSS), L13.2 (VSS), L14.2 (VSS), L15.2 (VSS), L16.2 (VSS), L17.2 (VSS), L18.2 (VSS), L19.2 (VSS), L20.2 (VSS), L21.2 (VSS), L22.2 (VSS), L23.2 (VSS), L24.2 (VSS), L25.2 (VSS), L26.2 (VSS), L27.2 (VSS), L28.2 (VSS), L29.2 (VSS), L30.2 (VSS), L31.2 (VSS), L32.2 (VSS), L33.2 (VSS), L34.2 (VSS), L35.2 (VSS), L36.2 (VSS), L37.2 (VSS), L38.2 (VSS), L39.2 (VSS), L40.2 (VSS), L41.2 (VSS), L42.2 (VSS), L43.2 (VSS), L44.2 (VSS), L45.2 (VSS), L46.2 (VSS), L47.2 (VSS), L48.2 (VSS), L49.2 (VSS), L50.2 (VSS), L51.2 (VSS), L52.2 (VSS), L53.2 (VSS), L54.2 (VSS), L55.2 (VSS), L56.2 (VSS), SW57.2, U1.3 (GND), U1.4 (GND), U1.23 (GND)
LED: L1.3 (DIN), U1.2 (RX)
unnamed: D1.2 (A), SW1.2
unnamed: D2.2 (A), SW2.2
unnamed: D3.2 (A), SW3.2
unnamed: D4.2 (A), SW4.2
unnamed: D5.2 (A), SW5.2
unnamed: D6.2 (A), SW6.2
unnamed: D7.2 (A), SW7.2
unnamed: D8.2 (A), SW8.2
unnamed: D9.2 (A), SW9.2
unnamed: D10.2 (A), SW10.2
unnamed: D11.2 (A), SW11.2
unnamed: D12.2 (A), SW12.2
unnamed: D13.2 (A), SW13.2
unnamed: D14.2 (A), SW14.2
unnamed: D15.2 (A), SW15.2
unnamed: D16.2 (A), SW16.2
unnamed: D17.2 (A), SW17.2
unnamed: D18.2 (A), SW18.2
unnamed: D19.2 (A), SW19.2
unnamed: D20.2 (A), SW20.2
unnamed: D21.2 (A), SW21.2
unnamed: D22.2 (A), SW22.2
unnamed: D23.2 (A), SW23.2
unnamed: D24.2 (A), SW24.2
unnamed: D25.2 (A), SW25.2
unnamed: D26.2 (A), SW26.2
unnamed: D27.2 (A), SW27.2
unnamed: D28.2 (A), SW28.2
unnamed: D29.2 (A), SW29.2
unnamed: D30.2 (A), SW30.2
unnamed: D31.2 (A), SW31.2
unnamed: D32.2 (A), SW32.2
unnamed: D33.2 (A), SW33.2
unnamed: D34.2 (A), SW34.2
unnamed: D35.2 (A), SW35.2
unnamed: D36.2 (A), SW36.2
unnamed: D37.2 (A), SW37.2
unnamed: D38.2 (A), SW38.2
unnamed: D39.2 (A), SW39.2
unnamed: D40.2 (A), SW40.2
unnamed: D41.2 (A), SW41.2
unnamed: D42.2 (A), SW42.2
unnamed: D43.2 (A), SW43.2
unnamed: D44.2 (A), SW44.2
unnamed: D45.2 (A), SW45.2
unnamed: D46.2 (A), SW46.2
unnamed: D47.2 (A), SW47.2
unnamed: D48.2 (A), SW48.2
unnamed: D49.2 (A), SW49.2
unnamed: D50.2 (A), SW50.2
unnamed: D51.2 (A), SW51.2
unnamed: D52.2 (A), SW52.2
unnamed: D53.2 (A), SW53.2
unnamed: D54.2 (A), SW54.2
unnamed: D55.2 (A), SW55.2
unnamed: D56.2 (A), SW56.2
unnamed: J1.2, L53.1 (DOUT)
unnamed: L1.1 (DOUT), L2.3 (DIN)
unnamed: L2.1 (DOUT), L3.3 (DIN)
unnamed: L3.1 (DOUT), L4.3 (DIN)
unnamed: L4.1 (DOUT), L8.3 (DIN)
unnamed: L5.1 (DOUT), L9.3 (DIN)
unnamed: L5.3 (DIN), L6.1 (DOUT)
unnamed: L6.3 (DIN), L7.1 (DOUT)
unnamed: L7.3 (DIN), L8.1 (DOUT)
unnamed: L10.1 (DOUT), L11.3 (DIN)
unnamed: L9.1 (DOUT), L10.3 (DIN)
unnamed: L11.1 (DOUT), L12.3 (DIN)
unnamed: L12.1 (DOUT), L16.3 (DIN)
unnamed: L13.1 (DOUT), L17.3 (DIN)
unnamed: L13.3 (DIN), L14.1 (DOUT)
unnamed: L14.3 (DIN), L15.1 (DOUT)
unnamed: L15.3 (DIN), L16.1 (DOUT)
unnamed: L17.1 (DOUT), L18.3 (DIN)
unnamed: L18.1 (DOUT), L19.3 (DIN)
unnamed: L19.1 (DOUT), L20.3 (DIN)
unnamed: L20.1 (DOUT), L24.3 (DIN)
unnamed: L21.1 (DOUT), L25.3 (DIN)
unnamed: L21.3 (DIN), L22.1 (DOUT)
unnamed: L22.3 (DIN), L23.1 (DOUT)
unnamed: L23.3 (DIN), L24.1 (DOUT)
unnamed: L25.1 (DOUT), L26.3 (DIN)
unnamed: L26.1 (DOUT), L27.3 (DIN)
unnamed: L27.1 (DOUT), L28.3 (DIN)
unnamed: L28.1 (DOUT), L32.3 (DIN)
unnamed: L29.1 (DOUT), L33.3 (DIN)
unnamed: L29.3 (DIN), L30.1 (DOUT)
unnamed: L30.3 (DIN), L31.1 (DOUT)
unnamed: L31.3 (DIN), L32.1 (DOUT)
unnamed: L33.1 (DOUT), L34.3 (DIN)
unnamed: L34.1 (DOUT), L35.3 (DIN)
unnamed: L35.1 (DOUT), L36.3 (DIN)
unnamed: L36.1 (DOUT), L40.3 (DIN)
unnamed: L37.1 (DOUT), L41.3 (DIN)
unnamed: L37.3 (DIN), L38.1 (DOUT)
unnamed: L38.3 (DIN), L39.1 (DOUT)
unnamed: L39.3 (DIN), L40.1 (DOUT)
unnamed: L41.1 (DOUT), L42.3 (DIN)
unnamed: L42.1 (DOUT), L43.3 (DIN)
unnamed: L43.1 (DOUT), L44.3 (DIN)
unnamed: L44.1 (DOUT), L48.3 (DIN)
unnamed: L45.1 (DOUT), L49.3 (DIN)
unnamed: L45.3 (DIN), L46.1 (DOUT)
unnamed: L46.3 (DIN), L47.1 (DOUT)
unnamed: L47.3 (DIN), L48.1 (DOUT)
unnamed: L49.1 (DOUT), L50.3 (DIN)
unnamed: L50.1 (DOUT), L51.3 (DIN)
unnamed: L51.1 (DOUT), L52.3 (DIN)
unnamed: L52.1 (DOUT), L56.3 (DIN)
unnamed: L53.3 (DIN), L54.1 (DOUT)
unnamed: L54.3 (DIN), L55.1 (DOUT)
unnamed: L55.3 (DIN), L56.1 (DOUT)
VCC: J1.1, L1.4 (VDD), L2.4 (VDD), L3.4 (VDD), L4.4 (VDD), L5.4 (VDD), L6.4 (VDD), L7.4 (VDD), L8.4 (VDD), L9.4 (VDD), L10.4 (VDD), L11.4 (VDD), L12.4 (VDD), L13.4 (VDD), L14.4 (VDD), L15.4 (VDD), L16.4 (VDD), L17.4 (VDD), L18.4 (VDD), L19.4 (VDD), L20.4 (VDD), L21.4 (VDD), L22.4 (VDD), L23.4 (VDD), L24.4 (VDD), L25.4 (VDD), L26.4 (VDD), L27.4 (VDD), L28.4 (VDD), L29.4 (VDD), L30.4 (VDD), L31.4 (VDD), L32.4 (VDD), L33.4 (VDD), L34.4 (VDD), L35.4 (VDD), L36.4 (VDD), L37.4 (VDD), L38.4 (VDD), L39.4 (VDD), L40.4 (VDD), L41.4 (VDD), L42.4 (VDD), L43.4 (VDD), L44.4 (VDD), L45.4 (VDD), L46.4 (VDD), L47.4 (VDD), L48.4 (VDD), L49.4 (VDD), L50.4 (VDD), L51.4 (VDD), L52.4 (VDD), L53.4 (VDD), L54.4 (VDD), L55.4 (VDD), L56.4 (VDD), U1.21 (VCC)
col0: SW1.1, SW8.1, SW15.1, SW22.1, SW29.1, SW36.1, SW43.1, SW50.1, U1.7 (D4)
col1: SW2.1, SW9.1, SW16.1, SW23.1, SW30.1, SW37.1, SW44.1, SW51.1, U1.10 (E6)
col2: SW3.1, SW10.1, SW17.1, SW24.1, SW31.1, SW38.1, SW45.1, SW52.1, U1.11 (B4)
col3: SW4.1, SW11.1, SW18.1, SW25.1, SW32.1, SW39.1, SW46.1, SW53.1, U1.14 (B2)
col4: SW5.1, SW12.1, SW19.1, SW26.1, SW33.1, SW40.1, SW47.1, SW54.1, U1.15 (B3)
col5: SW6.1, SW13.1, SW20.1, SW27.1, SW34.1, SW41.1, SW48.1, SW55.1, U1.16 (B1)
col6: SW7.1, SW14.1, SW21.1, SW28.1, SW35.1, SW42.1, SW49.1, SW56.1, U1.17 (F7)
reset: SW57.1, U1.22 (RST)
row0: D1.1 (K), D2.1 (K), D3.1 (K), D4.1 (K), D5.1 (K), D6.1 (K), D7.1 (K), U1.13 (B6)
row1: D8.1 (K), D9.1 (K), D10.1 (K), D11.1 (K), D12.1 (K), D13.1 (K), D14.1 (K), U1.8 (C6)
row2: D15.1 (K), D16.1 (K), D17.1 (K), D18.1 (K), D19.1 (K), D20.1 (K), D21.1 (K), U1.9 (D7)
row3: D22.1 (K), D23.1 (K), D24.1 (K), D25.1 (K), D26.1 (K), D27.1 (K), D28.1 (K), U1.1 (TX)
row4: D29.1 (K), D30.1 (K), D31.1 (K), D32.1 (K), D33.1 (K), D34.1 (K), D35.1 (K), U1.18 (F6)
row5: D36.1 (K), D37.1 (K), D38.1 (K), D39.1 (K), D40.1 (K), D41.1 (K), D42.1 (K), U1.6 (SCL)
row6: D43.1 (K), D44.1 (K), D45.1 (K), D46.1 (K), D47.1 (K), D48.1 (K), D49.1 (K), U1.12 (B5)
row7: D50.1 (K), D51.1 (K), D52.1 (K), D53.1 (K), D54.1 (K), D55.1 (K), D56.1 (K), U1.19 (F5)


Board: 2 copper layers, 272.0 x 86.0 mm, 179 parts (1 on the bottom side), 131 nets.

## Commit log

2022-01-08 pcb no copper
    [OLEDUKEY.kicad_pcb, RGB_Keys.sch]
2022-01-08 final commit (de momento)
    [OLEDUKEY.kicad_pcb]
2022-01-08 production files added
    [Key_matrix.sch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]
2022-01-09 added BOM
    [BOM.xlsx]
